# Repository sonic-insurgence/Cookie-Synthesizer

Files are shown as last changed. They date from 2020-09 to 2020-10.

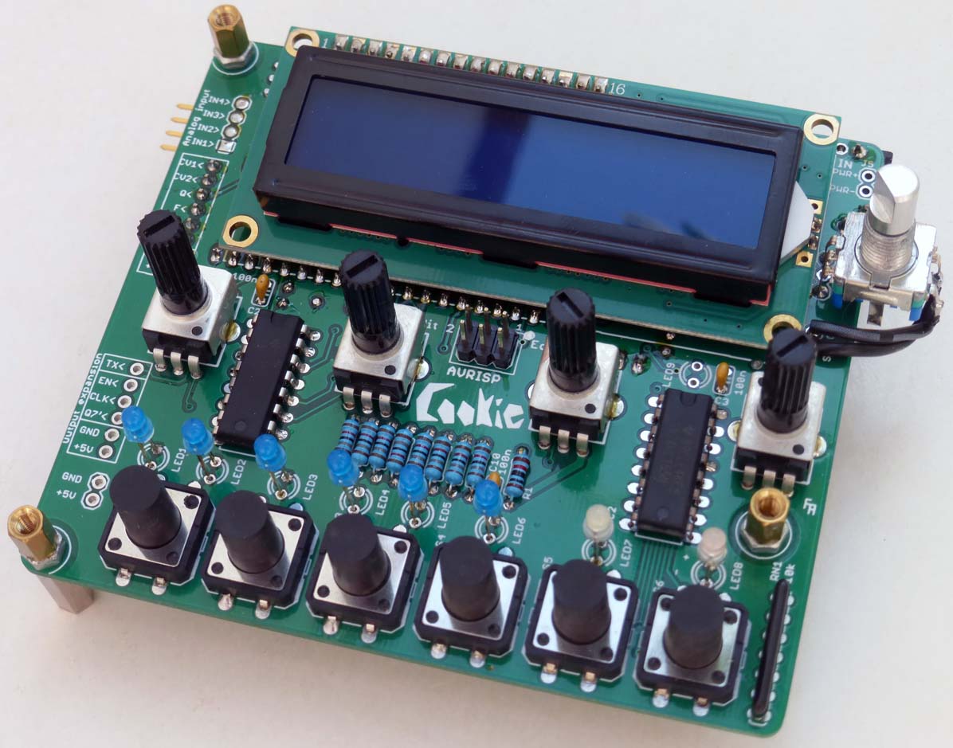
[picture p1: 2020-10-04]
documentation/images/controller board3.jpg

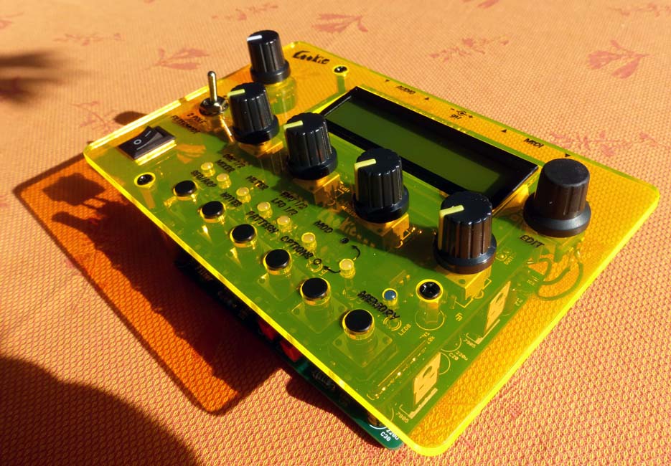
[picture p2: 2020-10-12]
documentation/images/Workshop Cookie Neon3.jpg

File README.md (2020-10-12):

# Cookie Synthesizer

The Cookie is a small but powerful DIY synthesizer project.
It is derived from the Shruthi-1 DIY hybrid synthesizer by Émilie Gillet 
from Mutable Instruments. 
Slight modifications have been carried out concerning the PCB form factor, the track layout 
and the arrangement of components. 
The circuit is basically the same as the "Shruthi-Digital-v08" with a "Shruthi-Analog-SMR4-mkII-v02" 
filter board.

### User Manual
Learn how to operate your Cookie Synth by having a look at the 
[user manual of the original Shruthi-1](https://mutable-instruments.net/archive/shruthi/manual/).

### Patch Editor
There are several editors out there that can be used to tweak the sounds on your Cookie Synth. 
E. g. check out the one from 
[Ixox (Win / OS X)](https://github.com/Ixox/Shruthi-And-Ambika-Editors/releases).
You may also find a patch manager software useful to organize your many sounds. 
If you are on Windows you might give  
[ShruthiFi1_0 (Win)](https://sites.google.com/site/thesonicfunk/programs) a try, although 
I had some issues with it.

### Firmware
The Cookie provides full software compatibility with Shruthi-1. You can flash the 
microcontroller with the original firmware from MI or with an alternative firmware like 
YAM by bjoeri. The software provided in this repository is a slight modification of the latter.
* https://github.com/pichenettes/shruthi-1
* https://github.com/bjoeri/shruthi-1

### Authors
* Author of the derived work, i. e. the Cookie synthesizer, is Sonic Insurgence.
* Author of the original work, i. e. the Shruthi-1 synthesizer, is Émilie Gillet.
* Author of the alternative firmware YAM is bjoeri.

### License
The Cookie schematics and PCB design files are licensed under a CreativeCommons CC-BY-SA license.
See: http://creativecommons.org/licenses/by-sa/3.0/

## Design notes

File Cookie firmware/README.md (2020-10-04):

# Cookie Synthesizer firmware

The Cookie Synth uses YAM0.05 alternative firmware for Shruthi-1 written by bjoeri.
I changed the splash screen to show "Cookie Synth" and removed "Mutable Instruments" because this is a registered trademark of Émilie Gillet.
To adapt for inverting opamps at the CV inputs the method "Ui::ScanPotentiometers()" in file "ui.cc" has been modified by adding the following line: 
```
    adc_.StartConversion(pots_multiplexer_address_);
    if (address >= 4) {
      value = 1023 - value;   // ### Cookie: invert external CV inputs CV1..4
      part.mutable_voice()->set_modulation_source(
          MOD_SRC_CV_1 + address - 4, value >> 2);
      address = 0xff;
    }
```

### User Manual
Have a look at the [user manual of the original Shruthi-1](https://mutable-instruments.net/archive/shruthi/manual/).

### YAM0.05 Differences / Improvements
Here's a short summary of changes compared to official Shruthi-1 firmware 1.02:

* PolyBlep implementations replace the original band-limited 'saw' and 'square' oscillators for higher fidelity and less memory footprint (Polyblep implementations inspired by, but less general than, Oliviers prototype for STM).
* 'square' is now a Polyblep oscillator with a more proper sounding PWM, i.e. more edginess, and no loudness drop for PWM modulation parameter above 0. (The original aliasing pwm is still available as 'dpwm'.)
* 'saw' is now a Polyblep oscillator (withuot any high pass pre-filtering and the modulation is different). The parameter for saw now add mix of a 2nd saw edge, resulting in a saw with sub oscillator (actually super oscillator) sound. 
* 'triangle' is no longer band-limited (to reduce memory footprint) and is folded (instead of clipped) upon modulation. This also means that the 'crush' oscillator is slightly different sounding.
* Added a 'csaw' Polyblep oscillator very similar to the CS-80 inspired saw oscillator for Braids. Without modulation it's a plain saw (identical to 'saw'). Modulation adds a 'notch' discontinuity before the ramp.
* Added a quad PWM oscillator ('qpwm') very similar to the quad saw ('pad'). The modulation parameter simultaneously affect both detuning of the four pwm oscillators, and the pulse width.
* Added an alternative FM oscillator ('fmfb') with feedback modulation. Just as for the regular FM oscillator, the modulation parameter defines the FM amount, but for modulation values above 64 increasing amount of feedback is added. At moderate levels the feedback adds 'grit'. At higher settings it adds digital distortion (deliberately left in).
* Added filter variations of CZ resonance saw and pulse waveforms ported from Ambika ('lpzsaw', 'pkzsaw', 'hpzsaw', 'lpzpulse', 'pkzpulse', 'hpzpulse'). In this new naming conventionm, the old 'zreso' is now named 'lpzsaw', and the old 'zpulse' is now named 'pkzpulse'.
* Added 'wavquence' oscillator (simply ported from the official Ambika firmware).
* Duo mode voice allocation reverted to 0.96 behaviour (because I subjectively think it's more enjoyable):
  - Press and hold C -> Osc1 plays C; then 
  - Press and hold E -> Osc2 plays C, Osc1 plays E 
  - (Sub is always assigned to lowest note)

Some tips on patch compatibility with official Shruthi-1 firmware:
Due to qualitative differences of the 'saw' and 'square' oscillators etc, levels may have to be adjusted somewhat to mimic original patches. If you really miss the original saw oscillator from the official firmware, this one is still available as 'oldsaw' (it's high-pass sampled and have a different character).

### How to make
- On a Mac install CrossPack-AVR with GCC Version 4.3.3: https://www.obdev.at/downloads/crosspack/CrossPack-AVR-20100115.dmg
- Connect an avrdude compatible programmer (e. g. AVRISP mkII) to the ISP connector on the Cookie and to a USB port on your computer.
Check the avrdude parameters in avrlib/makefile.mk.
- Use the terminal and go to the Cookie firmware directory.
- Make the bootloader first: make -f bootloader/makefile
- Then make the rest: make bake_all

### Authors
* Author of the original Shruthi-1 firmware is Émilie Gillet.
See https://github.com/pichenettes/shruthi-1
* Author of the alternative firmware YAM is bjoeri.
See https://github.com/bjoeri/shruthi-1

### License
The firmware is released under a GPL3.0 license. It includes a
reimplementation of the formant synthesis algorithm used in Peter Knight's
Cantarino speech synthesizer.

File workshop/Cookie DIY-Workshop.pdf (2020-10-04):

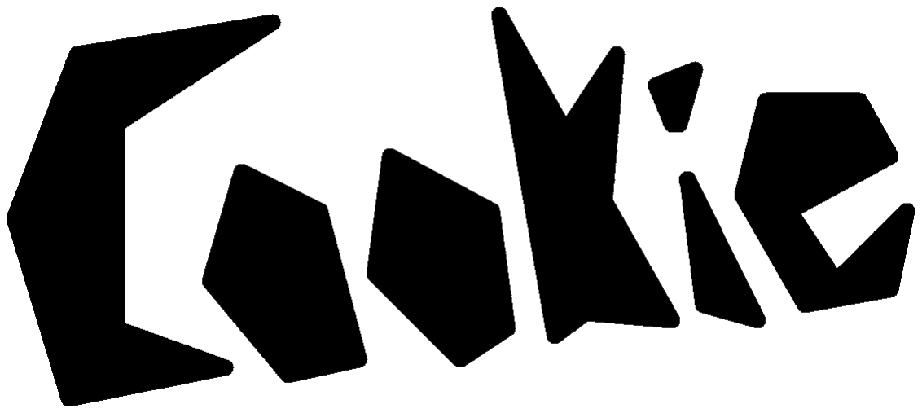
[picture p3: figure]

# Synthesizer DIY-Workshop

# Widerstand

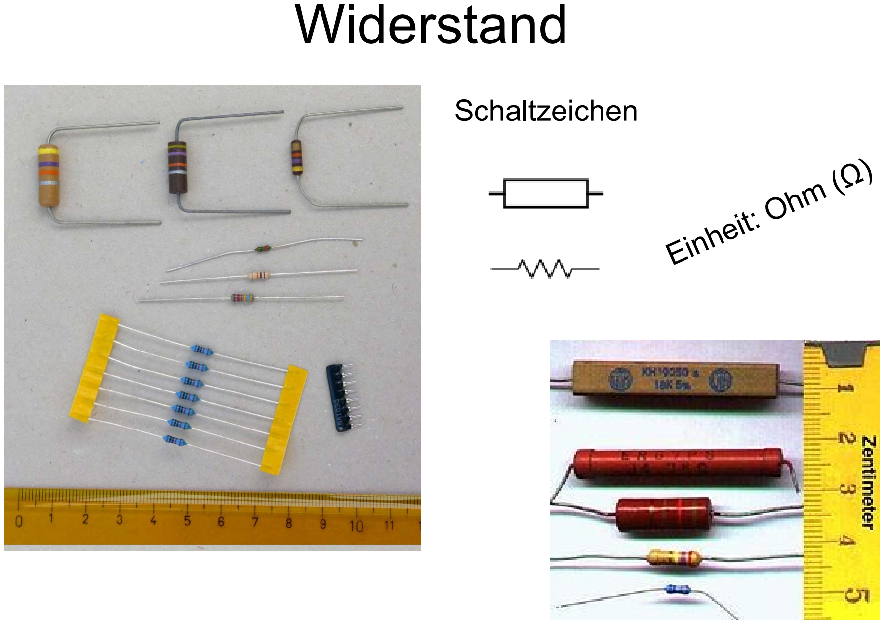
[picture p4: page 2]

Schaltzeichen
Einheit: Ohm (Ω)

# Kondensator

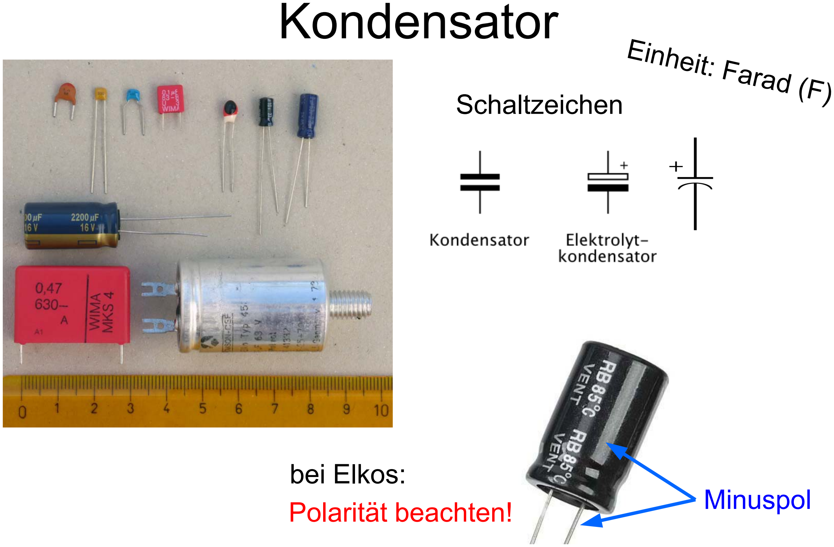
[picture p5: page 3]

Schaltzeichen

Einheit: Farad (F)

Polarität beachten!

bei Elkos:
Minuspol

# Diode

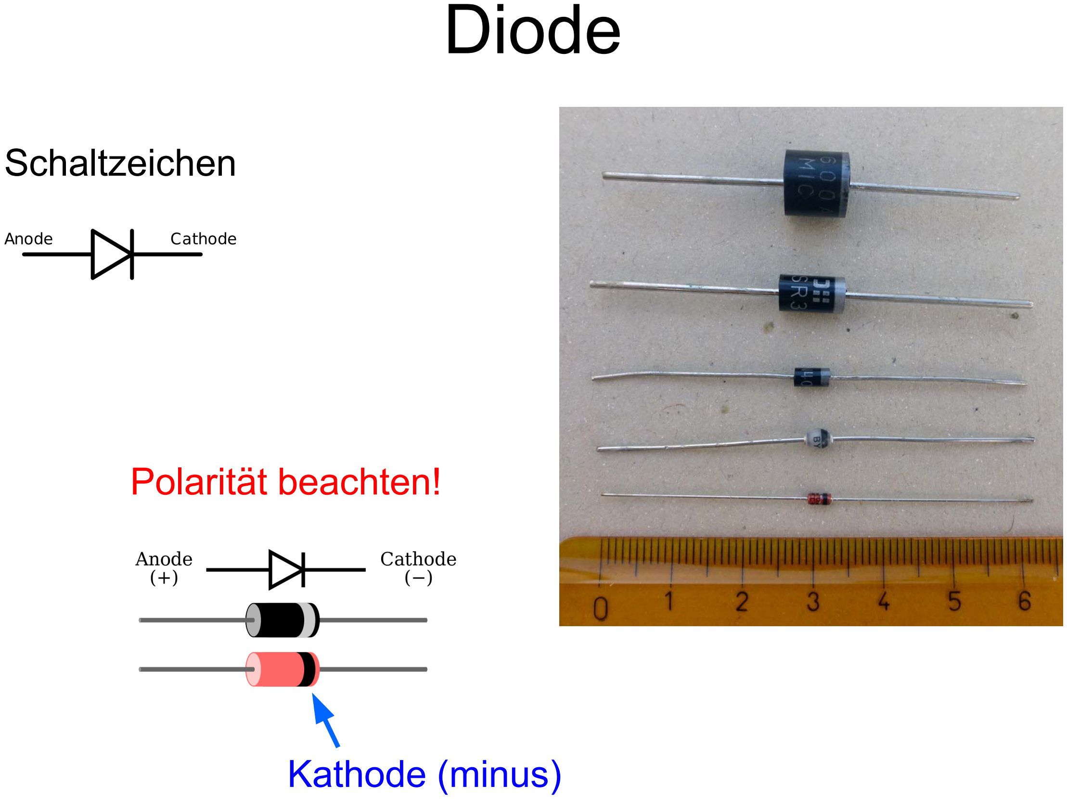
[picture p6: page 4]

Schaltzeichen

Polarität beachten!

Kathode (minus)

# Transistor

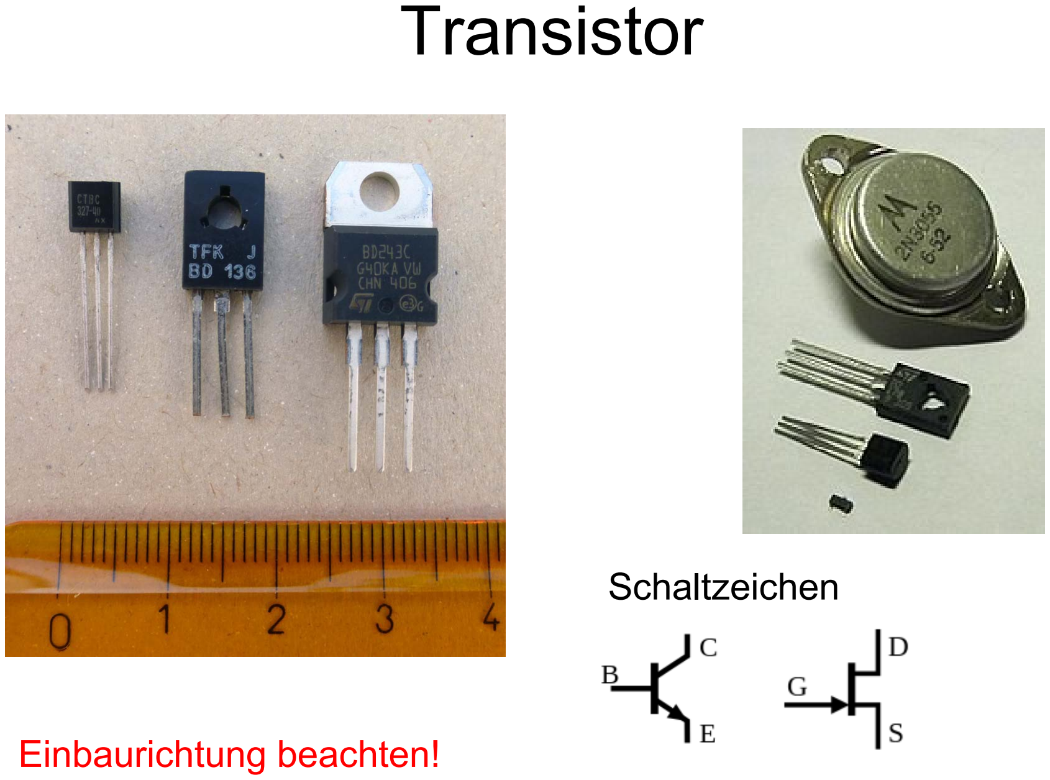
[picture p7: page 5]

Schaltzeichen

Einbaurichtung beachten!

# Integrierter Schaltkreis (IC)

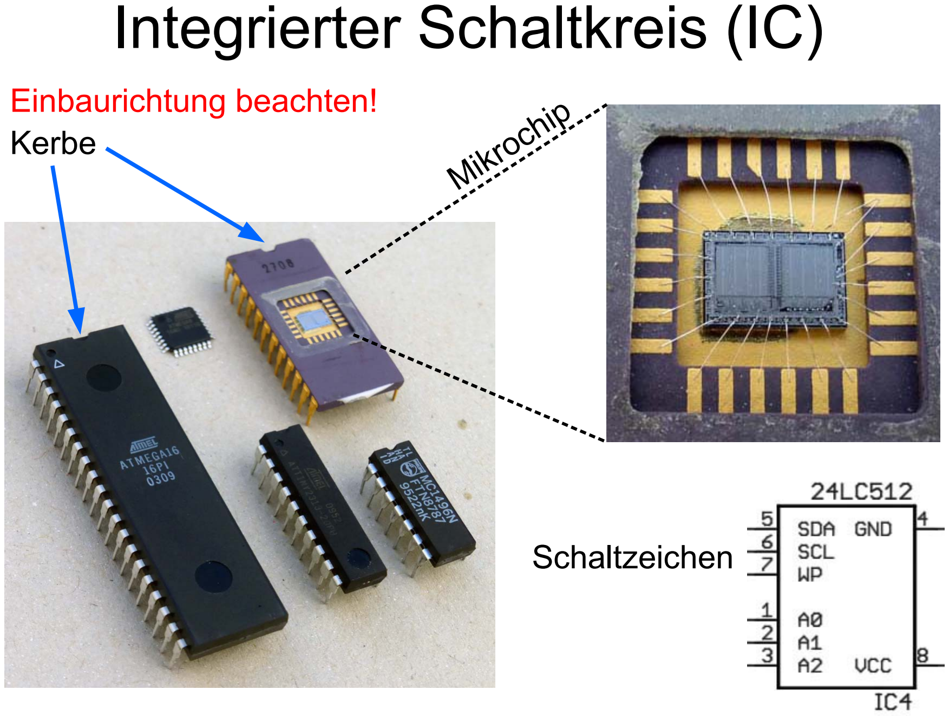
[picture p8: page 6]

Schaltzeichen

Mikrochip

Einbaurichtung beachten!
Kerbe

# Schaltplan lesen

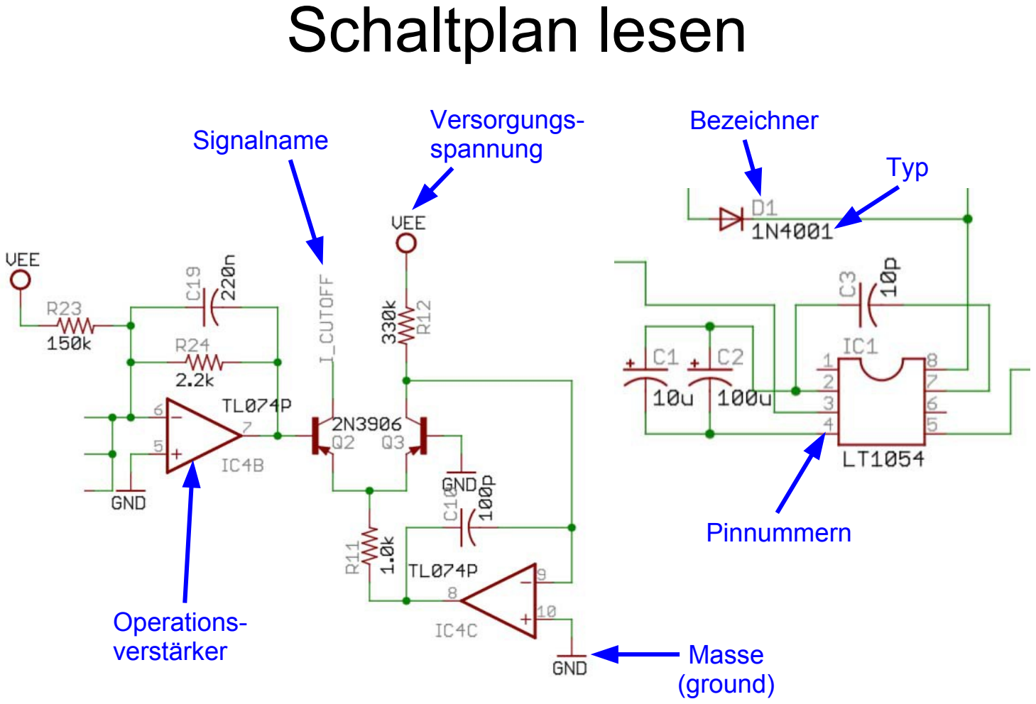
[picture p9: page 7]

Masse
(ground)

Bezeichner
Typ

Pinnummern

Signalname

Versorgungsspannung

Operationsverstärker

# BOM (bill of material)

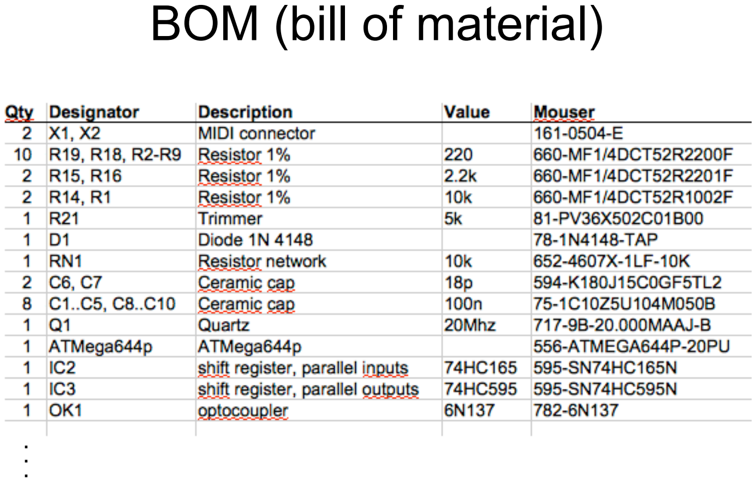
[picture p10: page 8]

# Einheiten

1 Ω
1 kΩ = 1.000 Ω
1 MΩ = 1.000.000 Ω

1 F
1 µF (mikro) = | 0.000001 F
1 nF (nano) = | 0.000000001 F
1 pF (pico) = 0.000000000001 F

Kurzschreibweise
4.7 kΩ → 4k7
2.2 MΩ → 2M2

Kurzschreibweise
6.8 µF → 6µ8 oder 6u8
100 nF → 100n
8.2 pF → 8p2

Bei den Kurzschreibweisen ergibt sich die Einheit
aus dem Schaltzeichen (Widerstand, Kondensator etc.).

# Kondensatorwerte

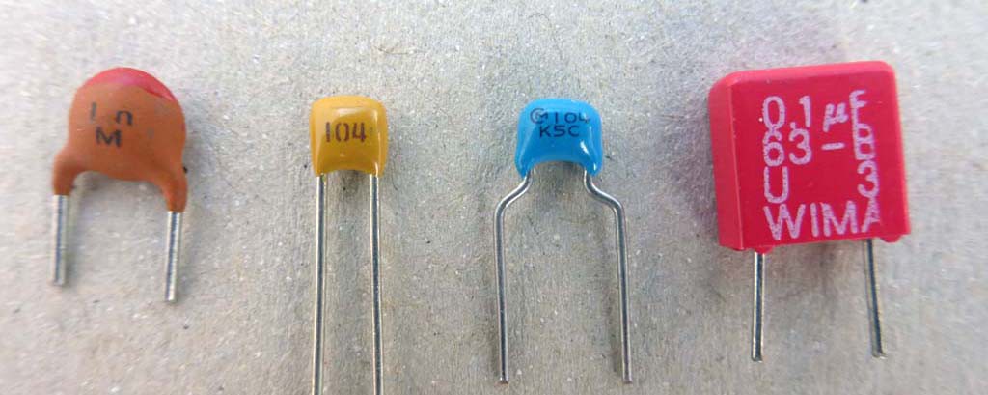
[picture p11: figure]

Die Art der Wertangabe von Kondensatoren variiert. 1 n → 1 nF
104 → 1 0 0000 pF = 100 nF
0.1 µF → So wünscht man sich das!

# Farbcode von Widerständen

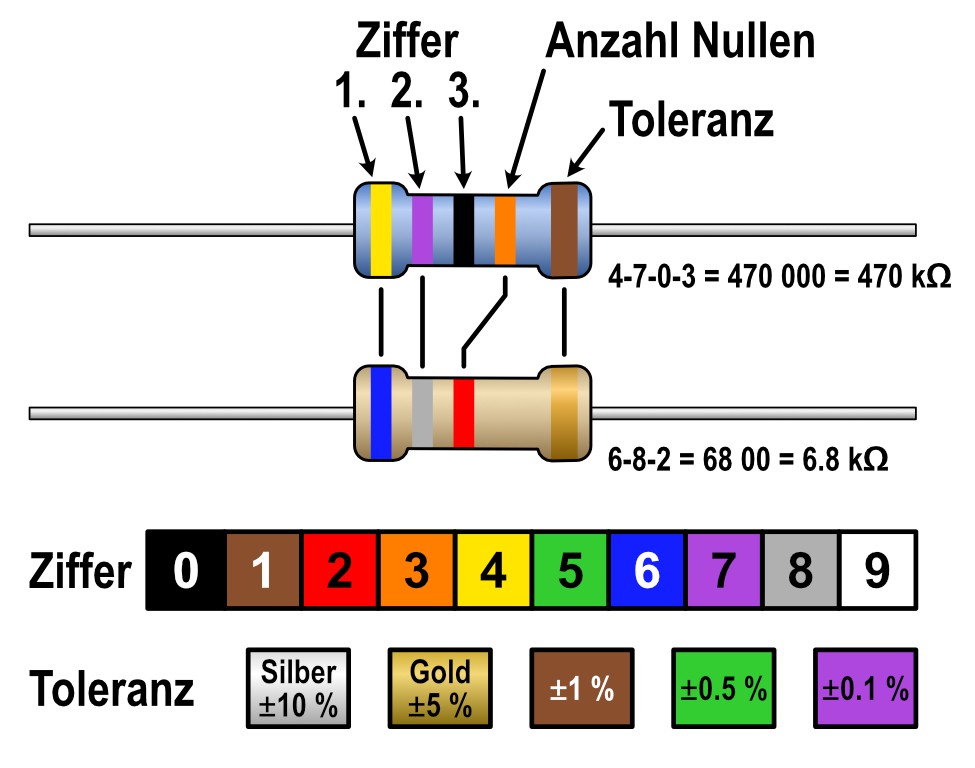
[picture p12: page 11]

# Übung Widerstandswerte

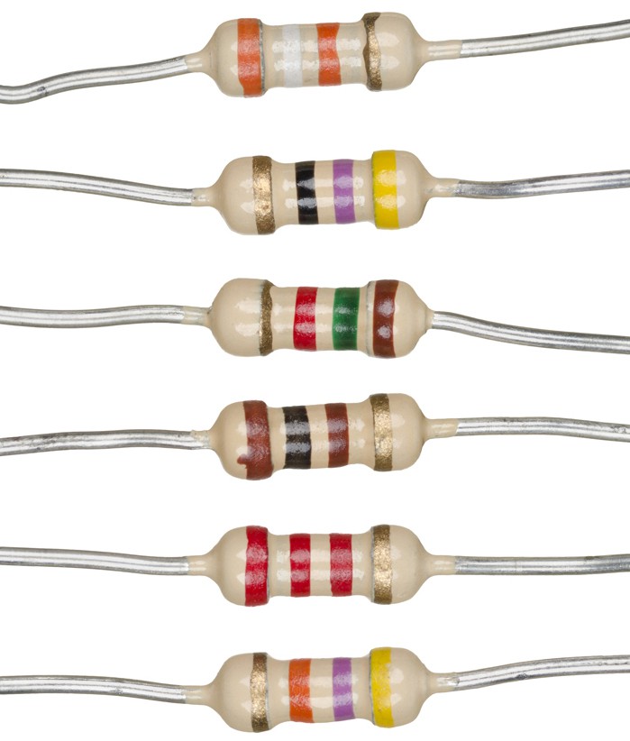
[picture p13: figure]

3-9-3 → 3 9 000 | = 39k
4-7-0 → 4 7 – | = 47
1-5-2 → 1 5 00 | = 1k5
1-0-1 → 1 0 0 | = 100
2-2-2 → 2 2 00 | = 2k2
4-7-3 → 4 7 000 | = 47 kΩ

alle: ±5 % Toleranz

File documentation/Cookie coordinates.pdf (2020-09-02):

Object | | | | | | Shruthi-1
| [mm] | [mm] | [mil] | [mil] | [mm]
| 99,7 | 87,6 | 3925 | 3450 | n. a. | no
| 3,2 | 3,2 | 125 | 125 | 3,0 | yes
| 3,2 | 84,5 | 125 | 3325 | 3,0 | yes
| 92,7 | 26,0 | 3650 | 1025 | 3,0 | no
| 12,1 | 39,4 | 475 | 1550 | 7,0 | yes
| 38,7 | 39,4 | 1525 | 1550 | 7,0 | yes
| 65,4 | 39,4 | 2575 | 1550 | 7,0 | yes
| 92,1 | 39,4 | 3625 | 1550 | 7,0 | yes
| 17,1 | 8,9 | 675 | 350 | 7,0 | yes
| 31,1 | 8,9 | 1225 | 350 | 7,0 | yes
| 45,1 | 8,9 | 1775 | 350 | 7,0 | yes
| 59,1 | 8,9 | 2325 | 350 | 7,0 | yes
| 73,0 | 8,9 | 2875 | 350 | 7,0 | yes
| 87,0 | 8,9 | 3425 | 350 | 7,0 | yes
LED1 | 12,7 | 19,1 | 500 | 750 | 3,0 | yes
LED2 | 21,0 | 19,1 | 825 | 750 | 3,0 | yes
LED3 | 31,1 | 19,1 | 1225 | 750 | 3,0 | yes
LED4 | 41,3 | 19,1 | 1625 | 750 | 3,0 | yes
LED5 | 49,5 | 19,1 | 1950 | 750 | 3,0 | yes
LED6 | 59,1 | 19,1 | 2325 | 750 | 3,0 | yes
LED7 | 73,0 | 19,1 | 2875 | 750 | 3,0 | yes
LED8 | 87,0 | 19,1 | 3425 | 750 | 3,0 | yes
LED9 | 80,0 | 46,4 | 3150 | 1825 | 3,0 | no
Midi In (X1) | 90,8 | 88,3 | 3575 | 3475 | 15,0 | yes
Midi Out (X2) | 70,5 | 88,3 | 2775 | 3475 | 15,0 | yes
| 10,2 | 87,6 | 400 | 3450 | 4,0 | yes
| 101,6 | 64,8 | 4000 | 2550 | 7,0 | yes
LCD pin1 | 20,7 | 83,4 | 815 | 3285 | n. a. | yes
center of LCD-screen | 52,7 | 67,4 | 71,5 x 24,5 | yes
CV1 | 6,4 | 64,8 | 250 | 2550 | yes
CV2 | 6,4 | 62,2 | 250 | 2450 | yes
Q | 6,4 | 59,7 | 250 | 2350 | yes
F | 6,4 | 57,2 | 250 | 2250 | yes
VCA | 6,4 | 54,6 | 250 | 2150 | yes
OSC | 6,4 | 52,1 | 250 | 2050 | yes
GND | 6,4 | 49,5 | 250 | 1950 | yes
+5V | 6,4 | 47,0 | 250 | 1850 | yes
TX | 6,4 | 31,1 | 250 | 1225 | yes
EN | 6,4 | 28,6 | 250 | 1125 | yes
CLK | 6,4 | 26,0 | 250 | 1025 | yes
Q7 | 6,4 | 23,5 | 250 | 925 | yes
GND | 6,4 | 21,0 | 250 | 825 | yes
+5V | 6,4 | 18,4 | 250 | 725 | yes
Shruthi-1
IN4 | 7,0 | 76,2 | 275 | 3000 | no | 250 | 2950
IN3 | 7,0 | 73,7 | 275 | 2900 | no | 250 | 2850
IN2 | 7,0 | 71,1 | 275 | 2800 | no | 250 | 2750
IN1 | 7,0 | 68,6 | 275 | 2700 | no | 250 | 2650

## Cookie Synth Dimensions

Origin: lower left corner

x-coord | y-coord | x-coord | y-coord | drill diameter
compatible
board size
spacer 1
spacer 2
spacer 3
potentiometer 1
potentiometer 2
potentiometer 3
potentiometer 4
push-button 1
push-button 2
push-button 3
push-button 4
push-button 5
push-button 6

LCD contrast (R21)
rotary encoder

pins of filter board connector

pins of spi connector

analog input pins | positions

Object
| [mm] | [mm] | [mil] | [mil] | [mm]
| 99,7 | 87,6 | 3925 | 3450 | n. a.
| 3,2 | 3,2 | 125 | 125 | 3,0
| 3,2 | 84,5 | 125 | 3325 | 3,0
| 92,7 | 26,0 | 3650 | 1025 | 3,0
audio in (J7) | 22,2 | 88,3 | 875 | 3475 | 11,0
audio out 1 (J8) | 40,6 | 88,3 | 1600 | 3475 | 11,0
audio out 2 (J9) | -2,4 | 20,1 | -95 | 790 | 11,0
| 54,6 | 88,3 | 2150 | 3475 | 6,0
| 0,0 | 35,6 | 0 | 1400 | 4,0

## Cookie Filter Dimensions

Origin: lower left corner

x-coord | y-coord | x-coord | y-coord | drill diameter

board size
spacer 1
spacer 2
spacer 3

supply (J1)
V/Oct (R33)

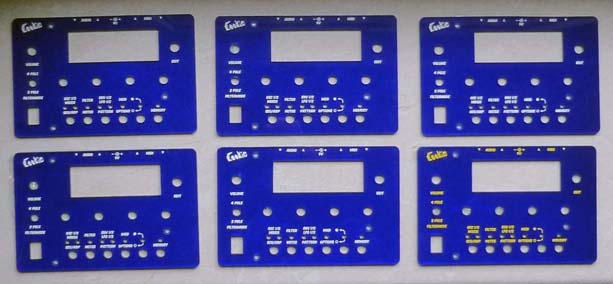
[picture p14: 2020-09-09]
documentation/images/Workshop Cookie Frontpanels.jpg

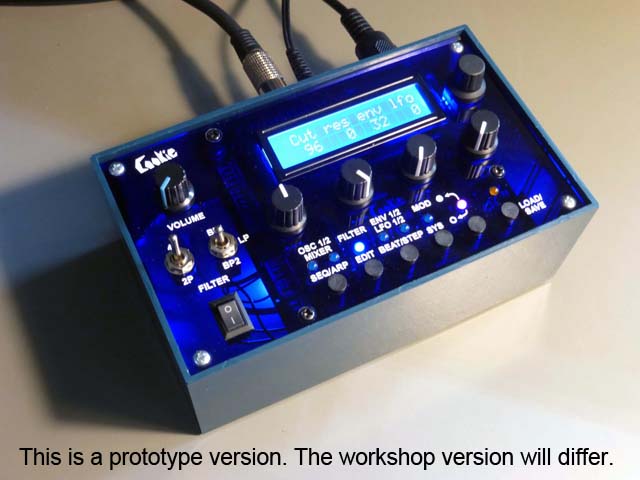
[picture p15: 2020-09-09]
documentation/images/Cookie Prototype.jpg

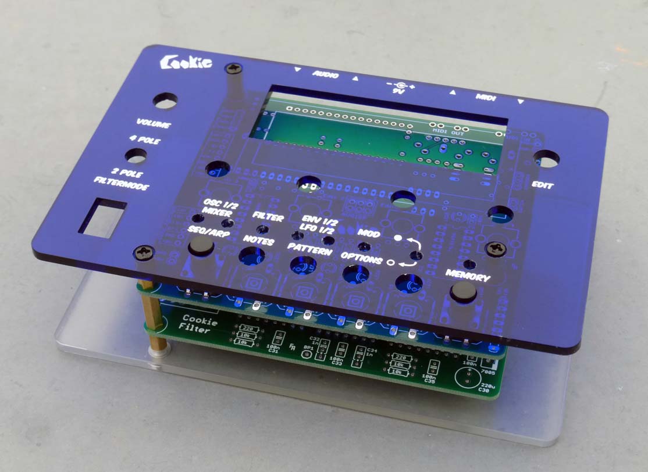
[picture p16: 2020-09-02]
documentation/images/Workshop Cookie Mockup2.jpg

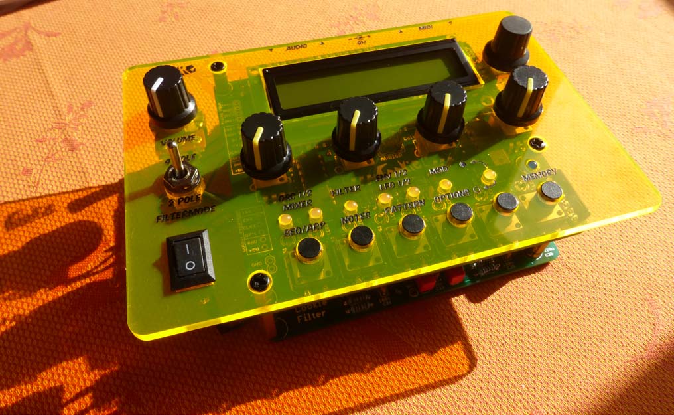
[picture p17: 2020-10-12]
documentation/images/Workshop Cookie Neon2.jpg

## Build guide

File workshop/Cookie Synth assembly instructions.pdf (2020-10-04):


# Bauanleitung

# Lötstellen

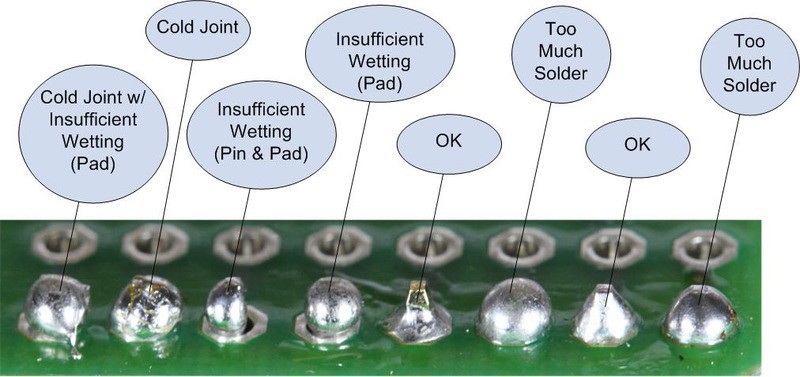
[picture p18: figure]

# Digital Controller Board

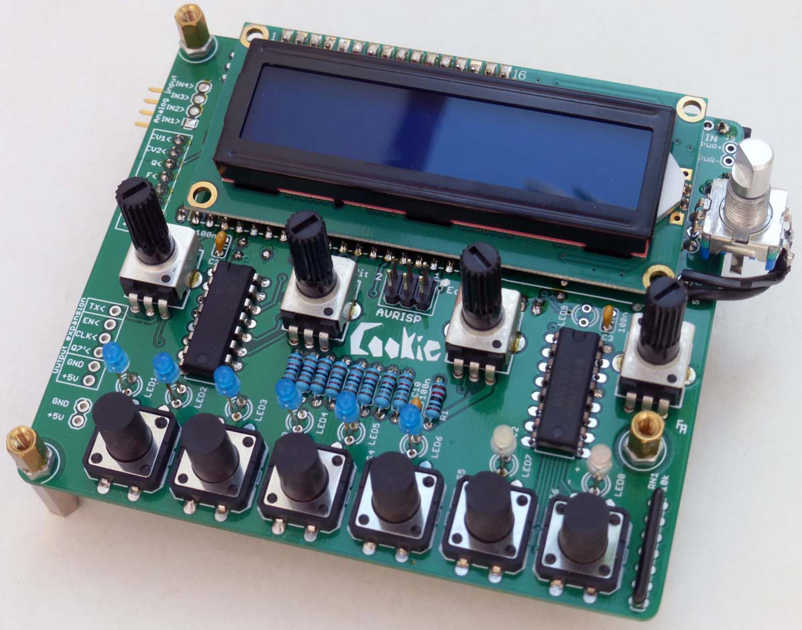
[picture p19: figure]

Cookie Synth – Controller Board | 4
R15, R16
→ 2.2 kΩ

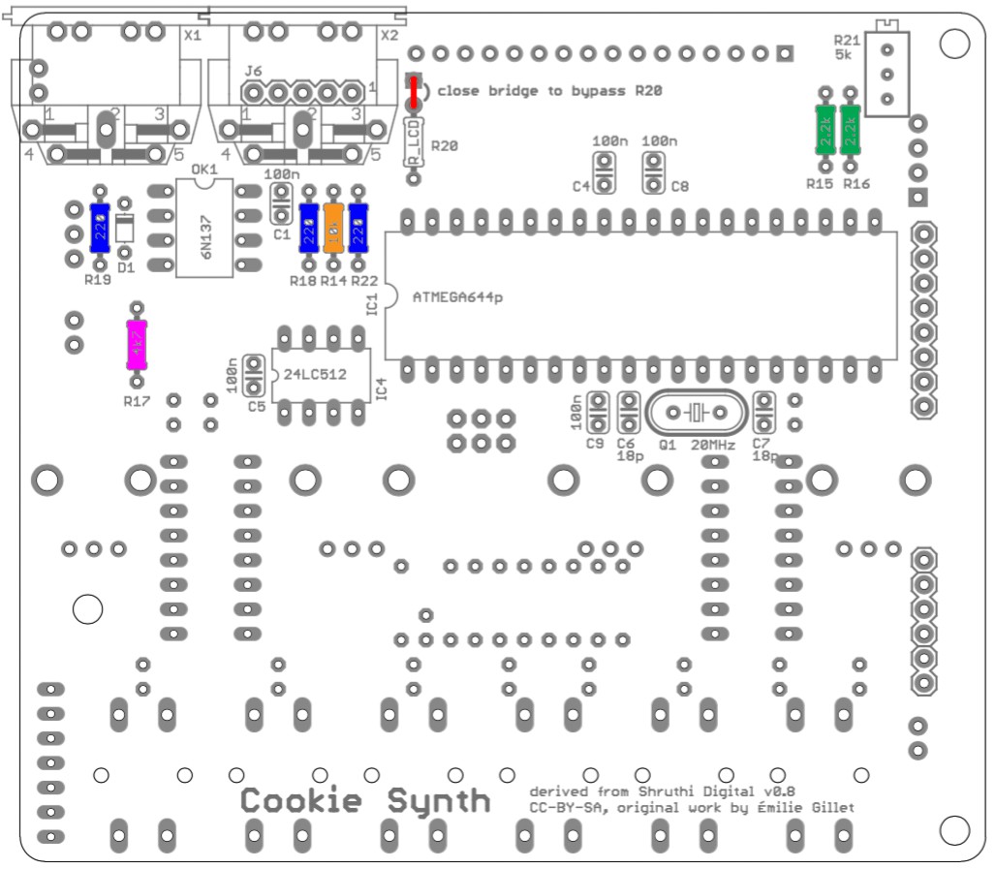
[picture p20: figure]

R18, R19, R22
→ 220 Ω

R17
→ 4.7 kΩ

R14
→ 10 kΩ

Drahtbrücke

Cookie Synth – Controller Board | 5
D1
→ 1N4148
Polarität
beachten!
| C1, C4, C5, C8,
C9
→ 100 nF
(Aufdruck 104)

Q1
→ 20 MHz

C6, C7
→ 18 pF
(Aufdruck 18)

Cookie Synth – Controller Board | 6
IC1, IC4, OK1
→ Sockel

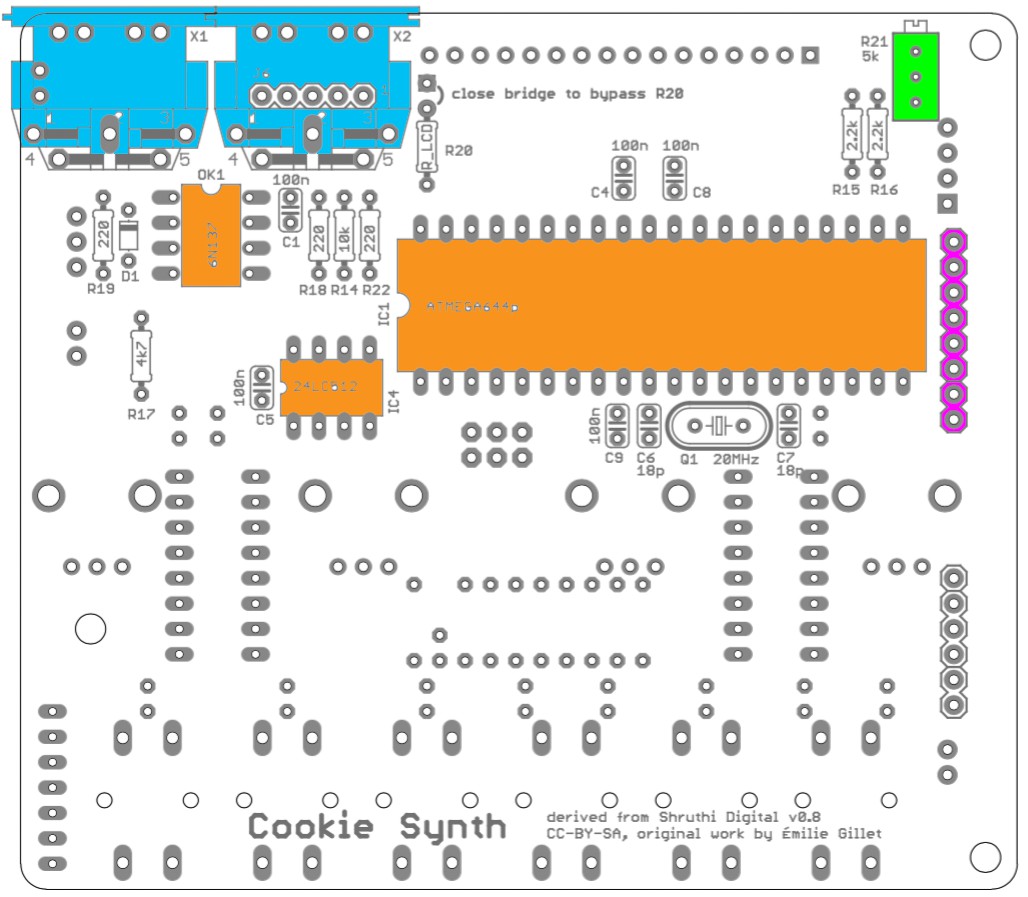
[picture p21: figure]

Auf richtige
Orientierung
(Kerbe im
Sockel) achten!

Stiftleiste
→ 8 Pins
(senkrecht zur
Platine)

R21
→ Trimmer 5 kΩ

X1, X2
→ DIN-Buchsen

Cookie Synth – Controller Board | 7

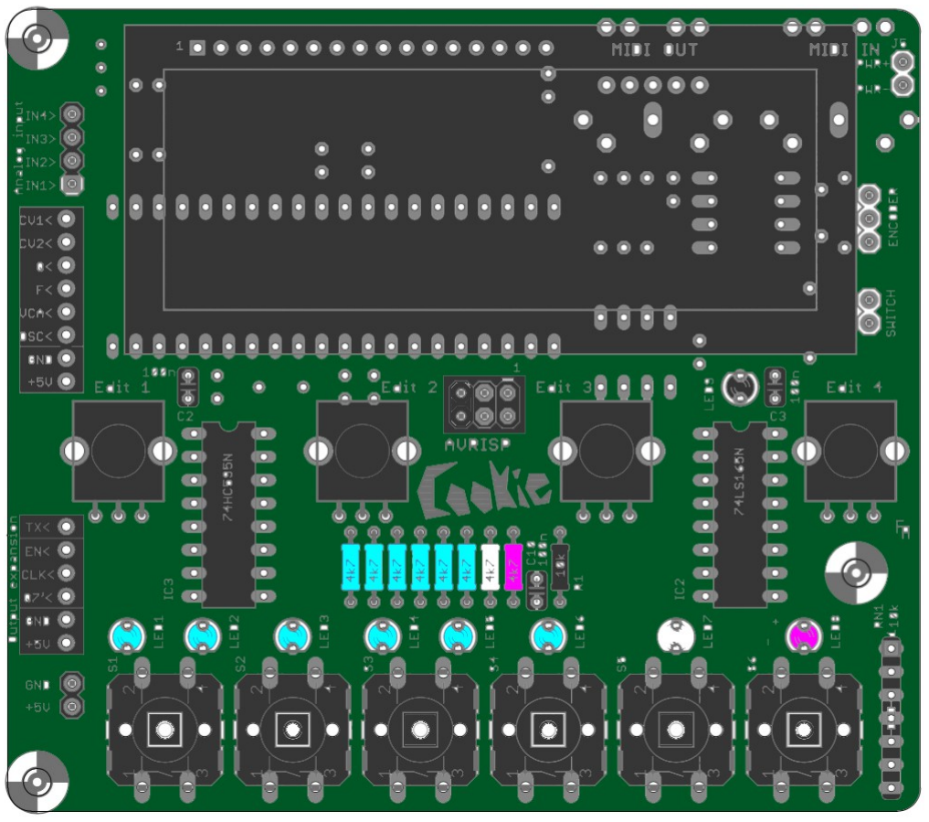
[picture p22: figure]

LED-Vorwiderstände

grün → 1 kΩ
gelb → 4.7 kΩ
rot → 10 kΩ
orange → 6.8 kΩ
blau → 18 kΩ
weiß → 15 kΩ
pink → 18 kΩ

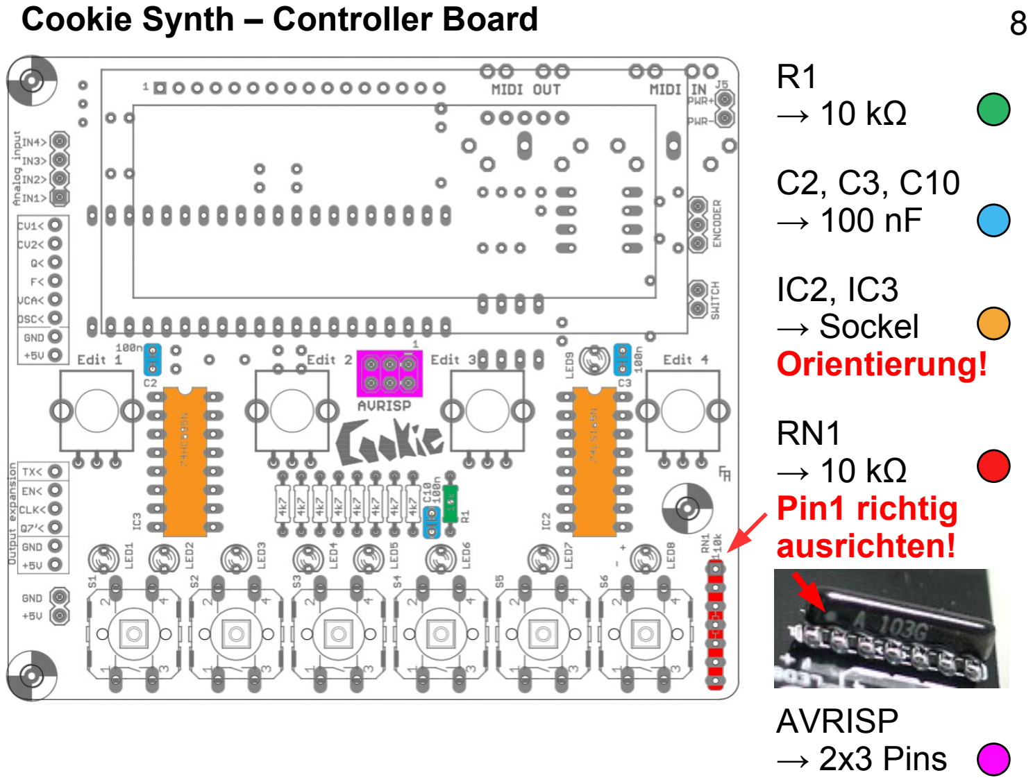
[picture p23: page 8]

Cookie Synth – Controller Board | 8
R1
→ 10 kΩ

C2, C3, C10
→ 100 nF

IC2, IC3
→ Sockel
Orientierung!

RN1
→ 10 kΩ
Pin1 richtig
ausrichten!

AVRISP
→ 2x3 Pins

Cookie Synth – Controller Board | 9
S1..6
→ Taster

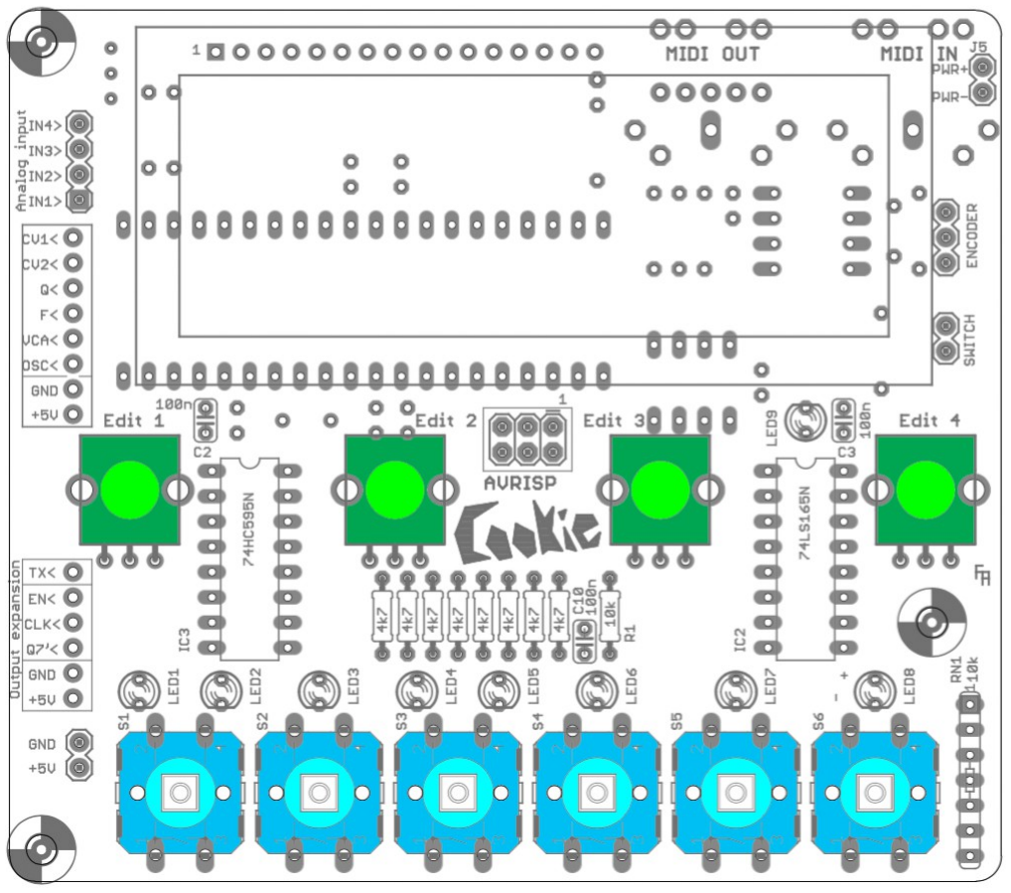
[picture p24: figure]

Edit1..4
→ Poti 10 kΩ

Hinweis:
Taster und
Potis müssen
flach aufliegen.

Cookie Synth – Controller Board | 10
| Bauteile zunächst nur
einsetzen:

ENCODER

LED1..8
| Polarität beachten!
langes Beinchen =
Anode (nach oben)
| abgeflachte Seite = Kathode (nach unten)

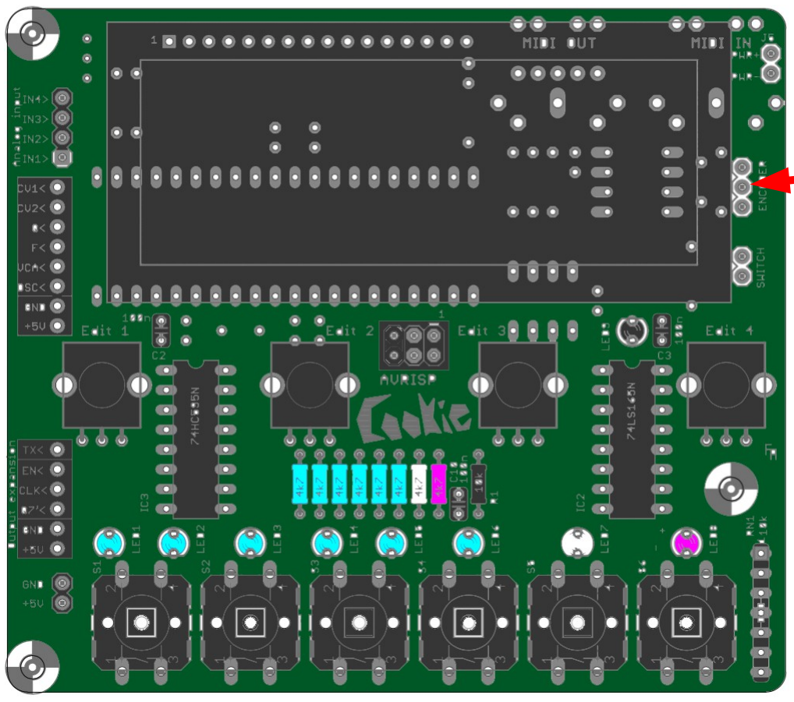
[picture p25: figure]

Hinweis: Vor dem Verlöten die Frontplatte provisorisch montieren und den Encoder lose anschrauben. Die LEDs in die Bohrungen führen, damit Position und Abstand stimmen. Dann löten.

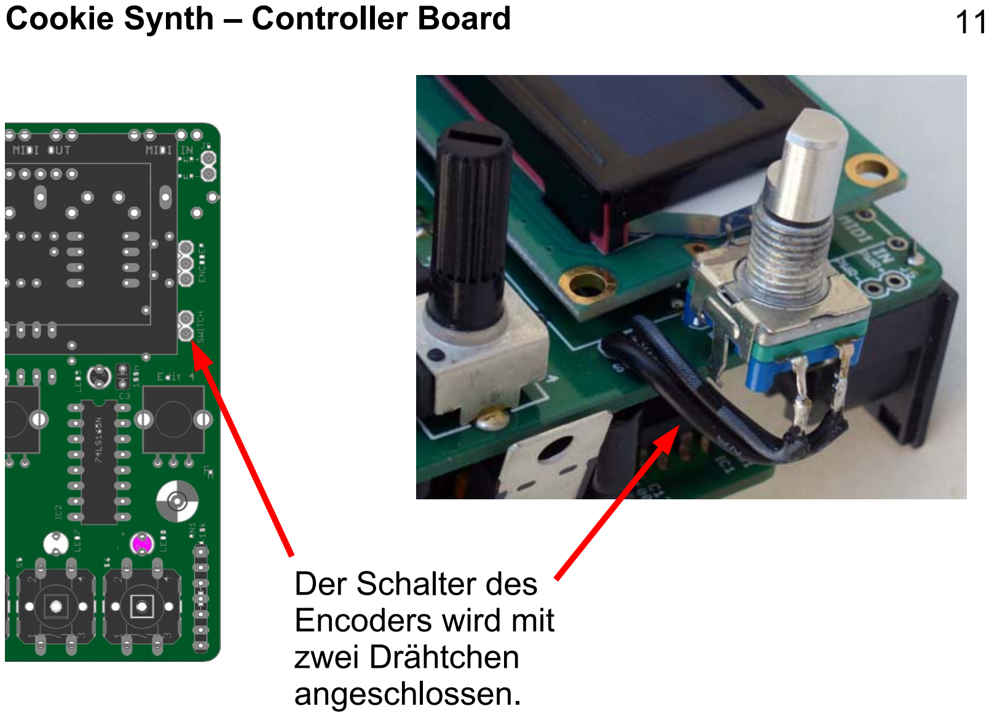
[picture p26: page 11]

Cookie Synth – Controller Board | 11

Der Schalter des
Encoders wird mit
zwei Drähtchen
angeschlossen.

Cookie Synth – Controller Board | 12
ICs einsetzen.
| Kerbe am IC muss mit der Kerbe am Sockel

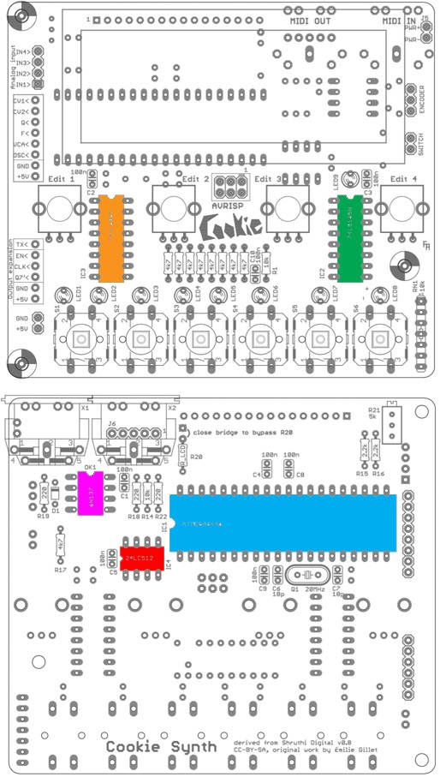
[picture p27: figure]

übereinstimmen.

IC1
→ ATmega644PA

IC2
→ 74HC165

IC3
→ 74HC595

IC4
→ 24LC512

OK
→ 6N137

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
Cookie Synth – Controller Board | 13

Funktionstest

1) An die Stiftleiste eine Spannung von 5 Volt anlegen
(GND = Minus, +5V = + 5 Volt).

→ Alle LEDs leuchten kurz auf. Danach leuchten LED3 und LED7 dauernd.

2) Tasten drücken und Encoder drehen.

→ Lightshow bewundern

Cookie Synth – Controller Board | 14 Stiftleiste (16-polig) mit den kurzen Stiftenden nur an den

beiden äußeren Pins senkrecht in die Platine löten.

| LCD einsetzen und in Front-
plattenöffnung einpassen.

Die Stiftleiste ist etwas abgewinkelt. Hierdurch kann
das LCD leicht geneigt
werden.

LCD von unten mit einem
| Lötpunkt fixieren, Frontplatte
entfernen und LCD fertig
einlöten.

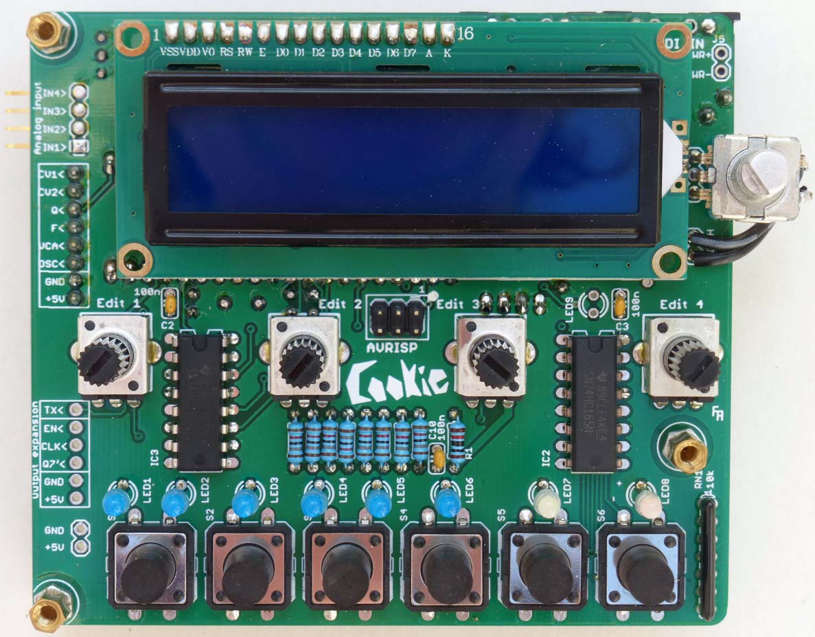
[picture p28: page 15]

Cookie Synth – Controller Board | 15

# Geschafft!

# Das erste Board

ist fertig.

# Analog Filter Board

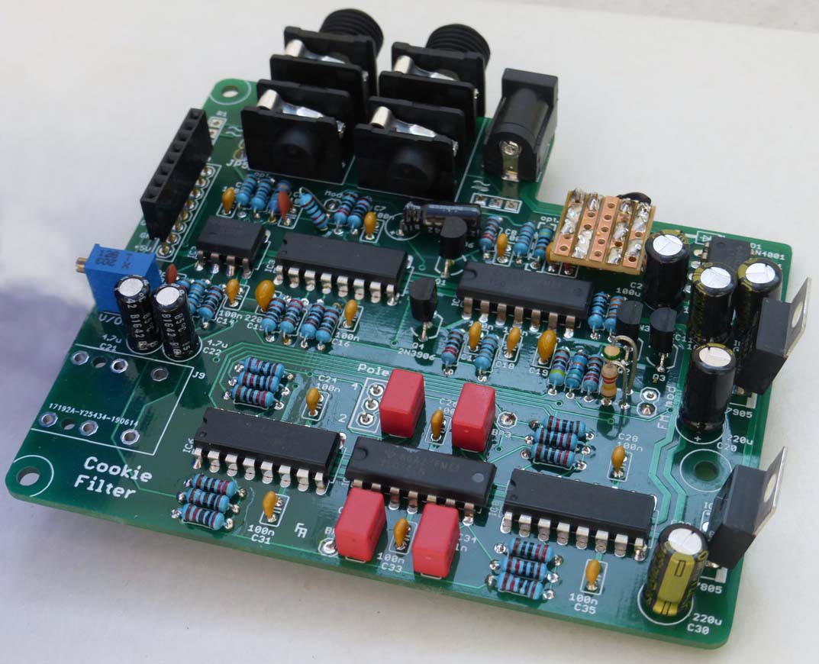
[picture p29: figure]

Cookie Synth – Filter Board | 18
D1
→ 1N4001
Polarität
beachten!

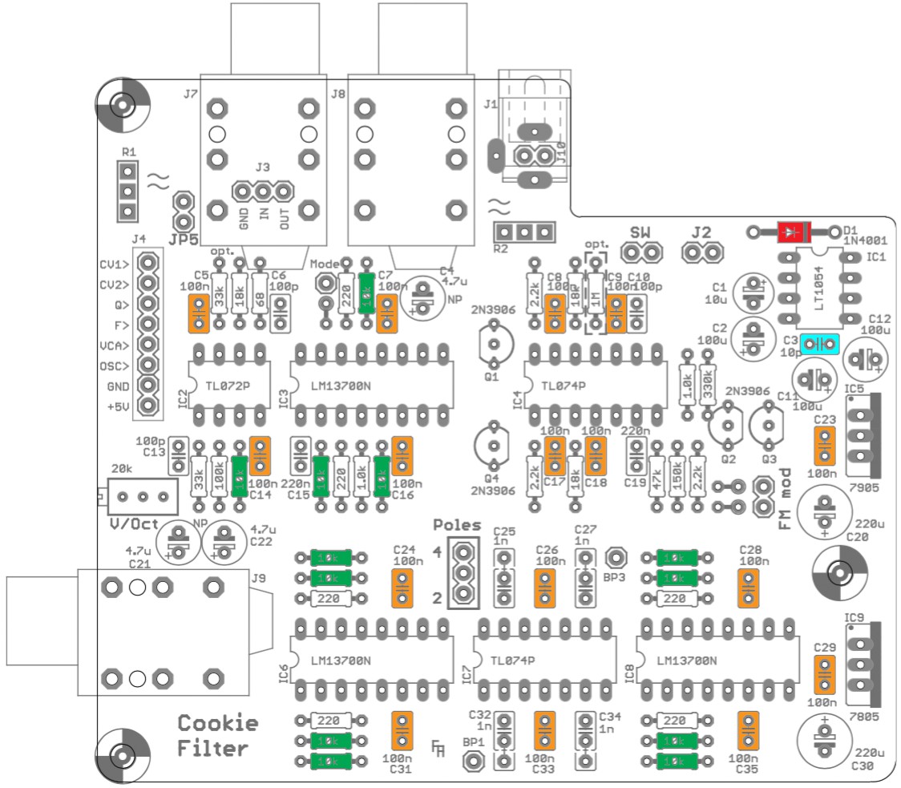
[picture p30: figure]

→ 12 x 10 kΩ

C3
→ 10 pF
(Aufdruck 10)
| C5, C7, C8, C9, C14, C16, C17, C18, C23, C24, C26, C28, C29, C31, C33, C35 → 16 x 100 nF (Aufdruck 104)

Cookie Synth – Filter Board | 19
1 x 68 Ω

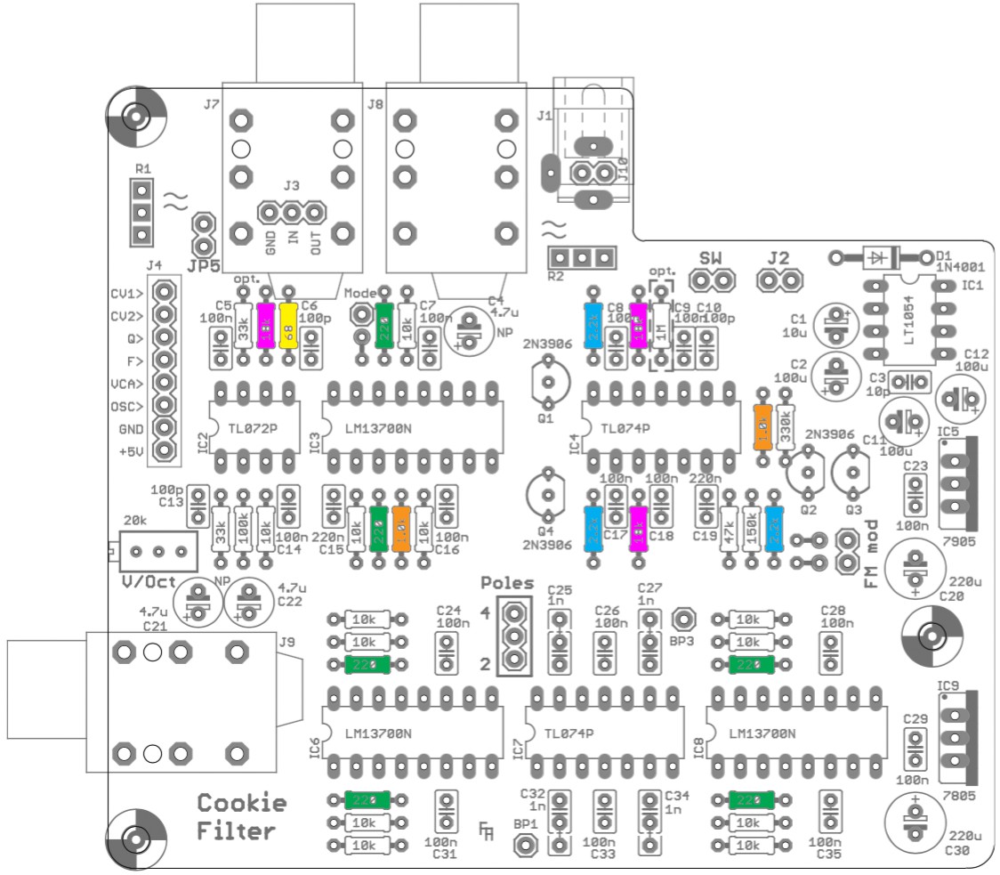
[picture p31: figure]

6 x 220 Ω

2 x 1 kΩ

3 x 2.2 kΩ

3 x 18 kΩ

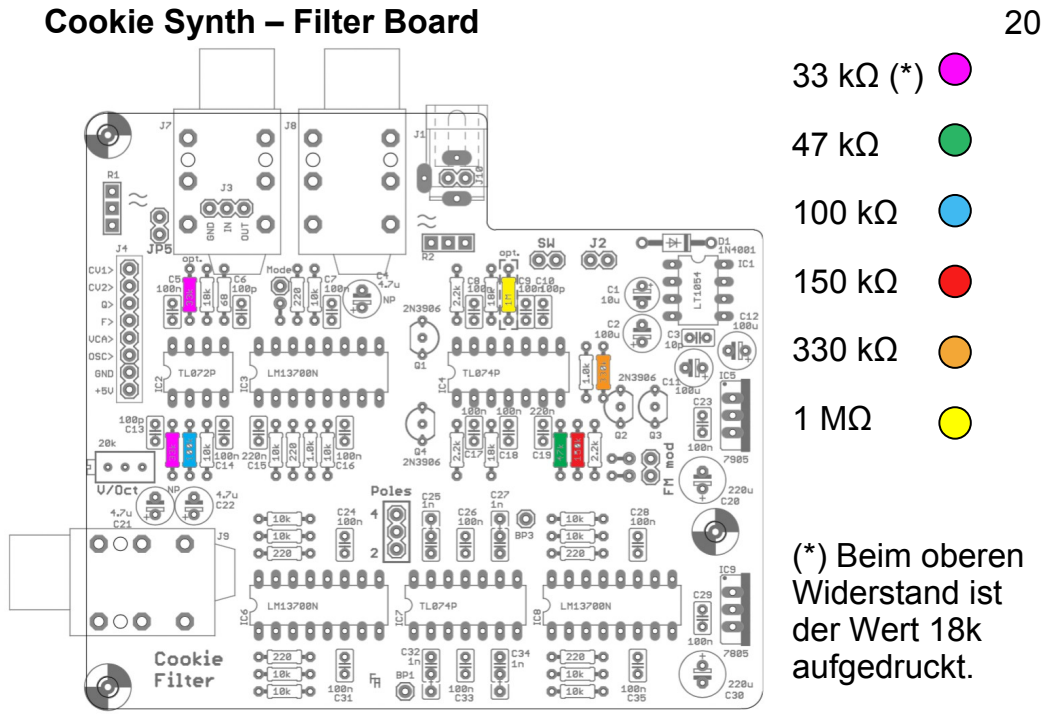
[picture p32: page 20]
Cookie Synth – Filter Board; (*) Beim oberen Widerstand ist der Wert 18k aufgedruckt.

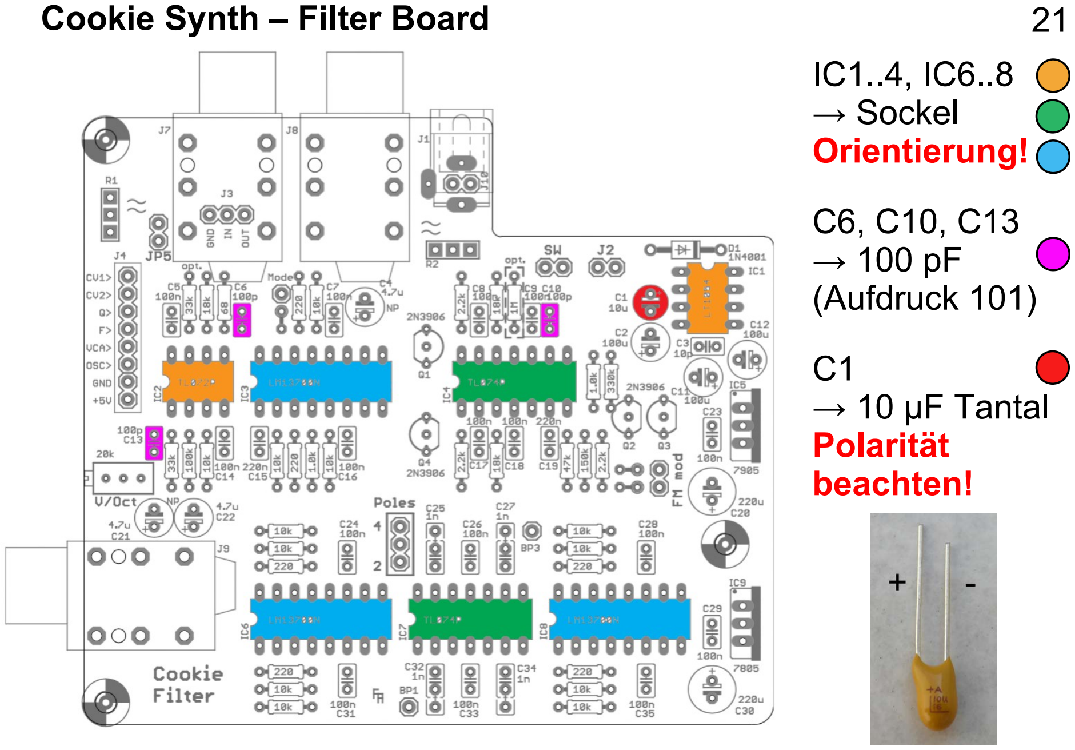
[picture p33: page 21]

Cookie Synth – Filter Board | 21
IC1..4, IC6..8
→ Sockel
Orientierung!

C6, C10, C13
→ 100 pF
| (Aufdruck 101)

C1
| → 10 µF Tantal
Polarität
beachten!

Cookie Synth – Filter Board | 22
C15, C19
→ 220 nF
(Aufdruck 224)

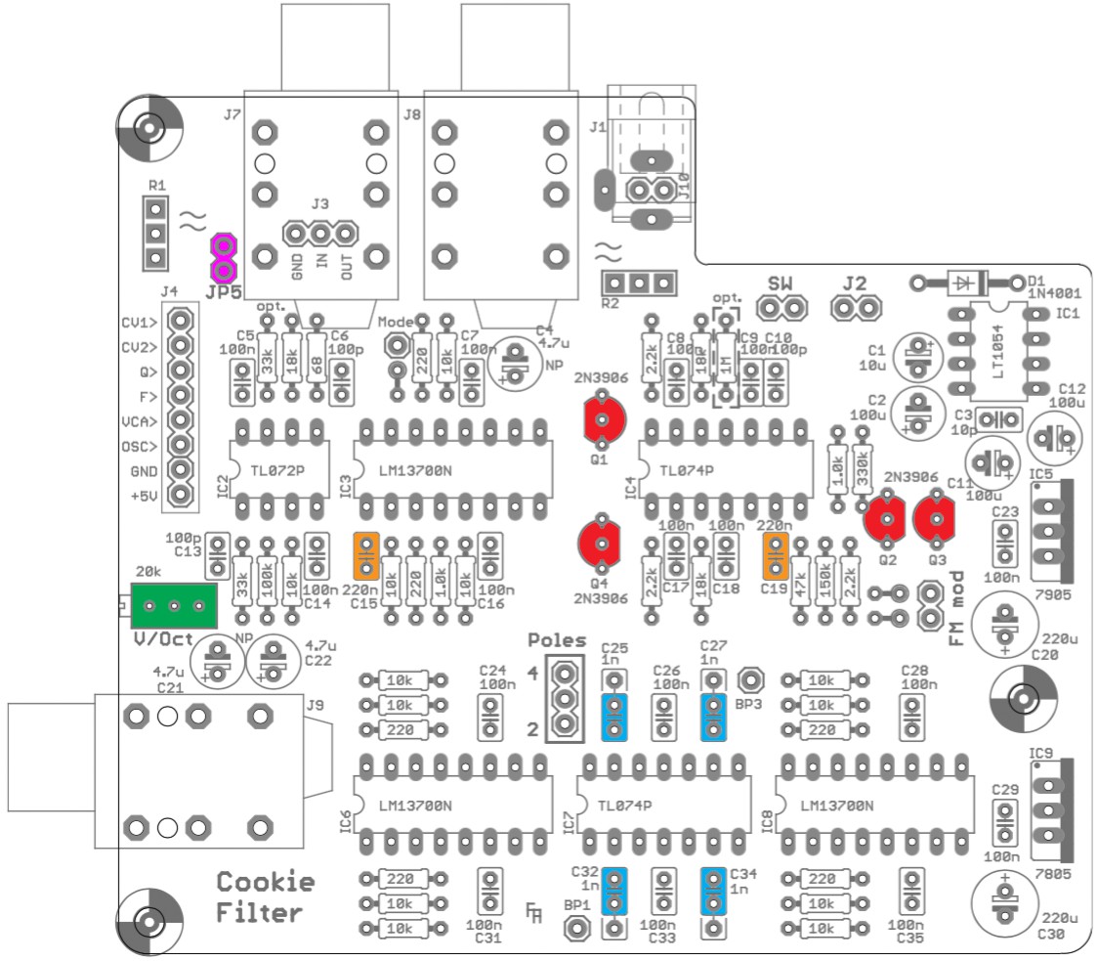
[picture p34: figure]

C25, C27, C32,
C34
→ 1 nF
| (rotes Klötzchen)

Q1..4
→ 2N3906
Orientierung!

JP5
→ Pfostenleiste

R33
| → Trimmer 20 kΩ

Cookie Synth – Filter Board | 23
C4, C21, C22
→ 4.7 µF
| (bipolare Elkos,
Polarität egal)
C4 liegend!

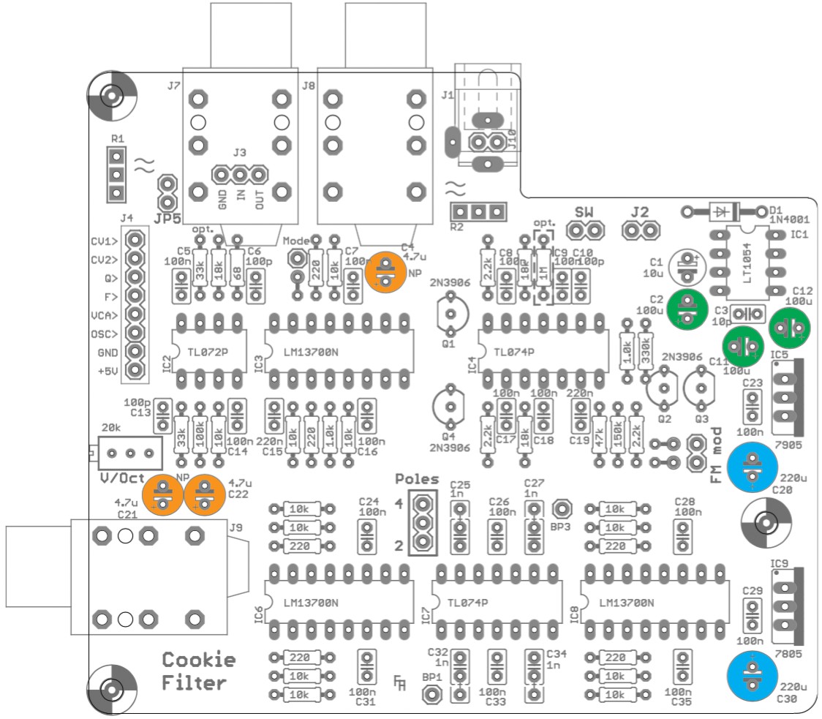
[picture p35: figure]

C2, C11, C12
→ 100 µF
Polarität
beachten!

C20, C30
→ 220 µF
Polarität
beachten!

100 µF und
220µF sehen
gleich aus!

Cookie Synth – Filter Board | 24
J1
→ DC-Buchse

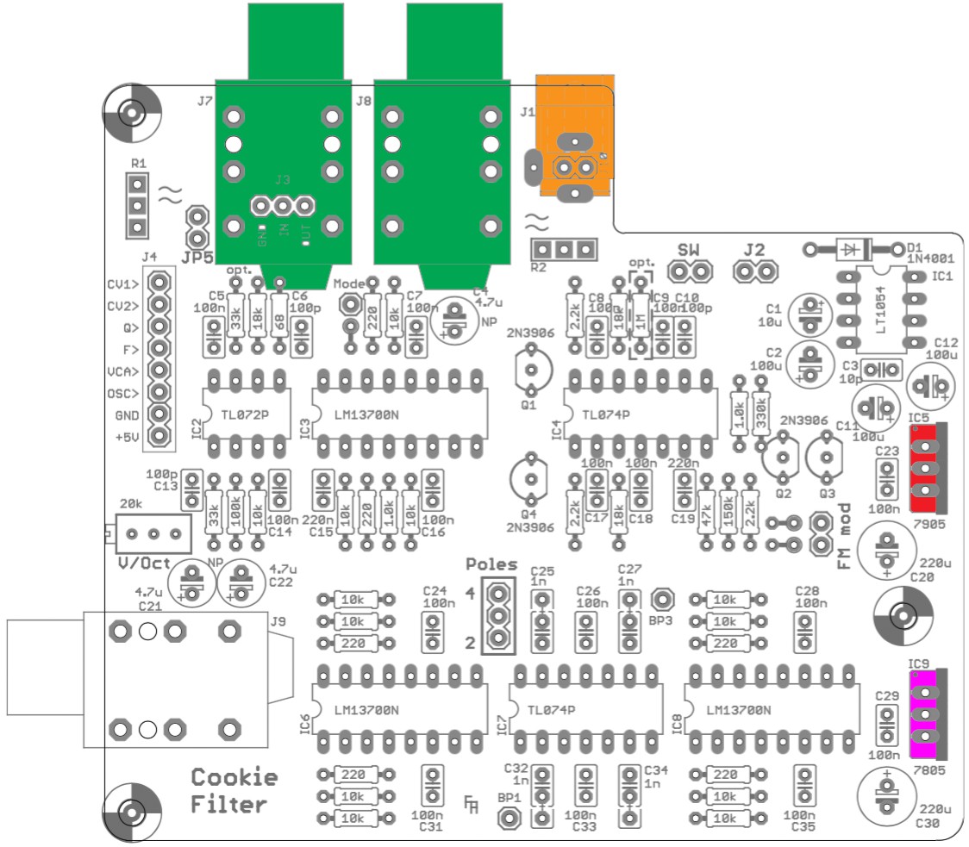
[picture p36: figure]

J7, J8
→ 6.3 mm-
| Klinkenbuchse

IC5
→ 7905
Orientierung!

IC9
→ 7805
Orientierung!

Cookie Synth – Filter Board | 25 Die folgenden Bau-

elemente werden
über kleine Kabel
mit dem Filter-
| Board verbunden.

SW
| → Wippenschalter

Poles
→ Kippschalter

R2
→ Potentiometer
10 kΩ
4,7 kΩ zwischen
Links und Mitte

Cookie Synth – Filter Board | 26
IC1 (LT1054)
einsetzen

9 V-Netzteil
anschließen
Polarität
beachten!

Spannung
messen:
| GND (Masse)

+5 Volt

-5 Volt

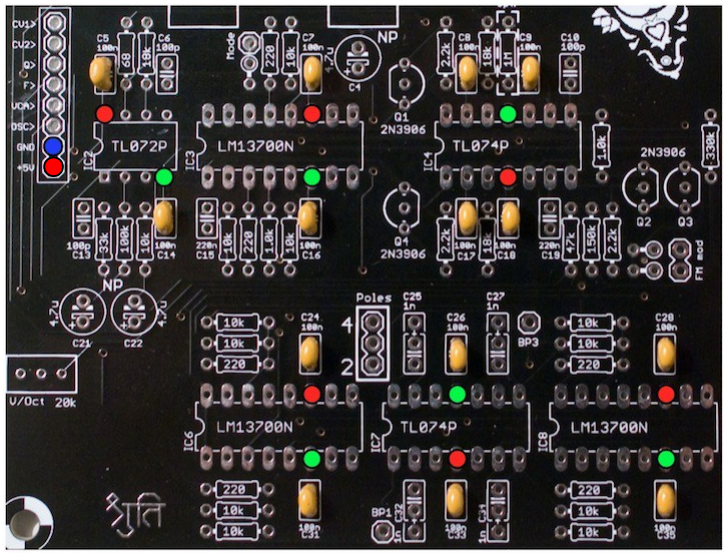
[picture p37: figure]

Alles OK?
→ dann die restlichen ICs einsetzen
Kerbe am IC muss mit der Kerbe im Sockel übereinstimmen!

Cookie Synth – Filter Board | 27
J4
→ Buchsenleiste

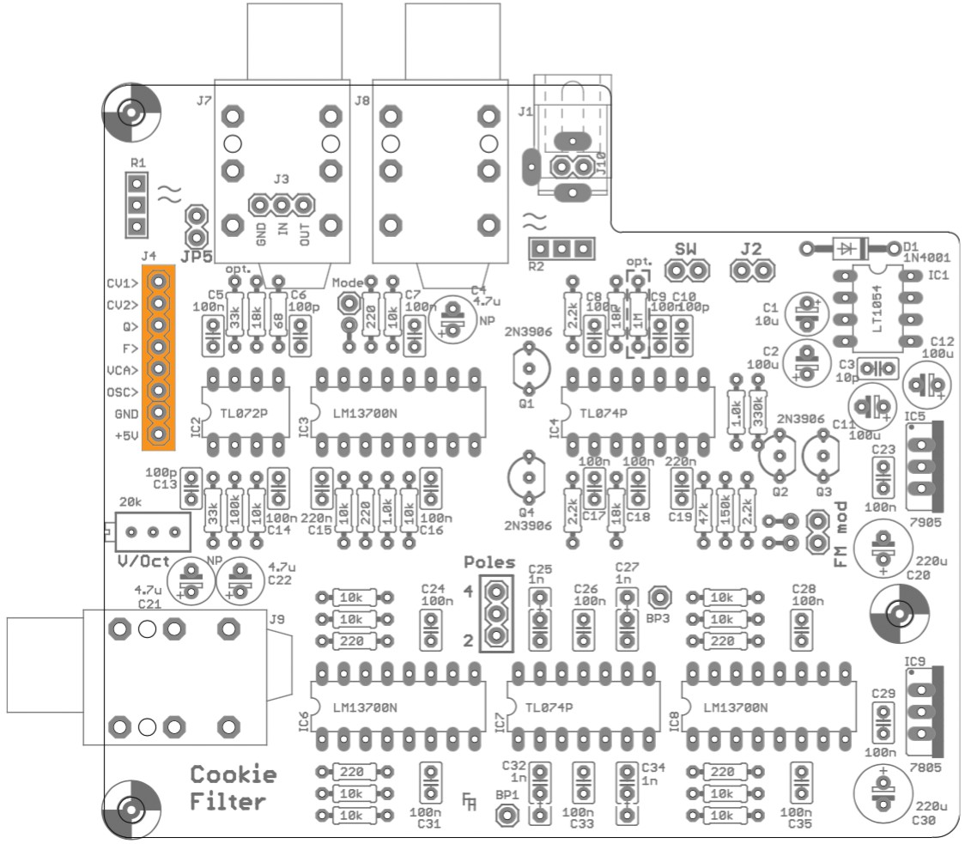
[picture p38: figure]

Vorgehensweise

1) Die Buchsenleiste auf
die Stiftleiste der
Controllerplatine
aufstecken.
2) Beide Platinen mit 20
mm-Distanzhülsen
| übereinander montieren.
3) Buchsenleiste auf
| dem Filterboard verlöten.

Cookie Synth – Filter Board | 28

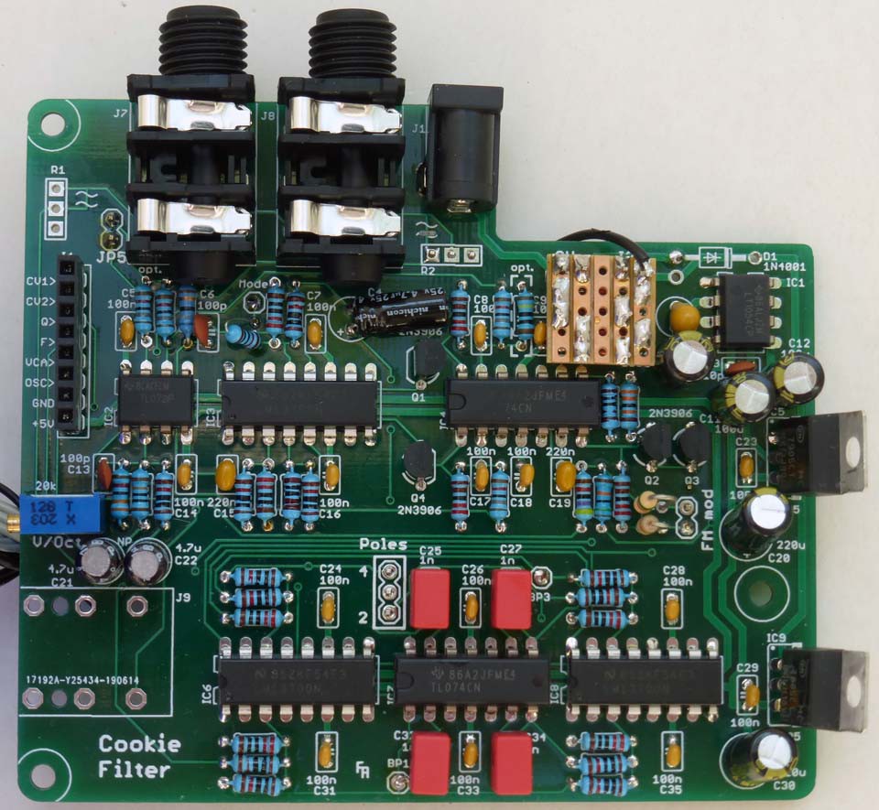
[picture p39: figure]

# Bravo!

# Wir sind kurz vor

dem Ziel.

Cookie Synth – Zusammenbau | 30

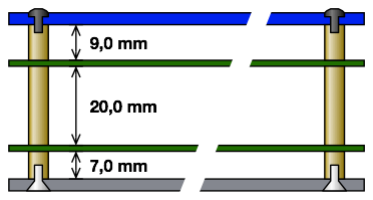
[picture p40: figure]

Schrauben „mit Gefühl“ anziehen, damit das Plexiglas nicht reißt / bricht.

Cookie Synth – Kalibration | 31

Ein Keyboard anschließen.

Am Cookie folgendes
einstellen:

Oscillator 1 shape: none
Oscillator 2 shape: none
Filter cutoff: 64
Filter resonance: 63
Filter envelope and LFO
modulations: 0

Auf dem Keyboard ein
Oktav-Intervall spielen
und den V/Oct-Trimmer
so verstellen, dass auch
eine Oktave zu hören ist.

# Herzlichen

# Glückwunsch!

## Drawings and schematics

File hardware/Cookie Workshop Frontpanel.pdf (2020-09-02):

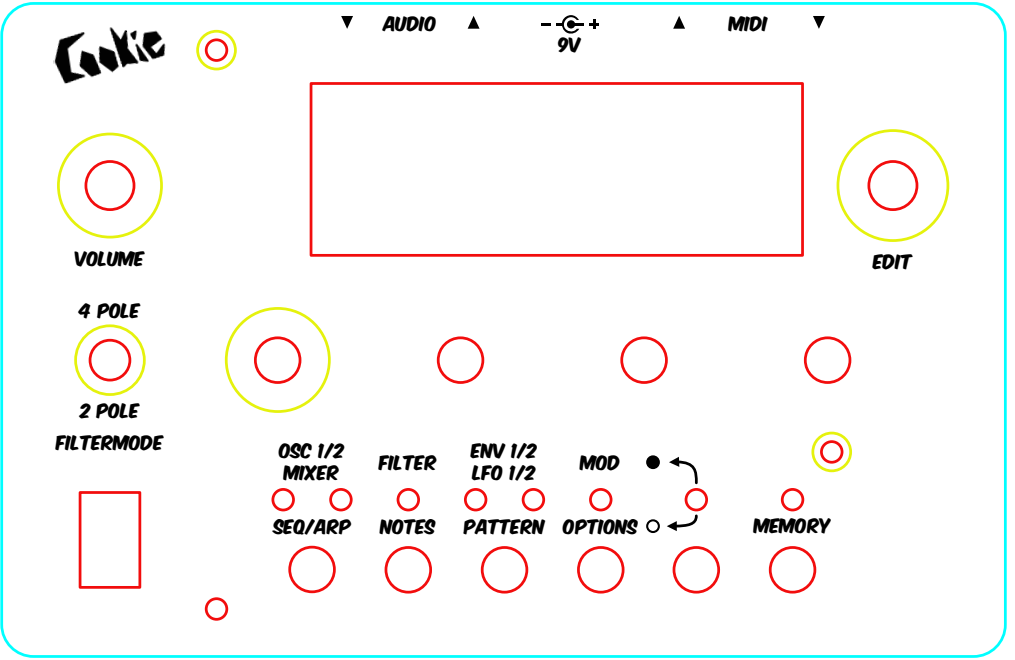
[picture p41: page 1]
VOLUME; FILTERMODE; OSC 1/2; MIXER; FILTER; MOD; MEMORY; EDIT; MIDI; AUDIO; SEQ/ARP; NOTES; PATTERN OPTIONS; ENV 1/2 LFO 1/2; 4 POLE; 2 POLE

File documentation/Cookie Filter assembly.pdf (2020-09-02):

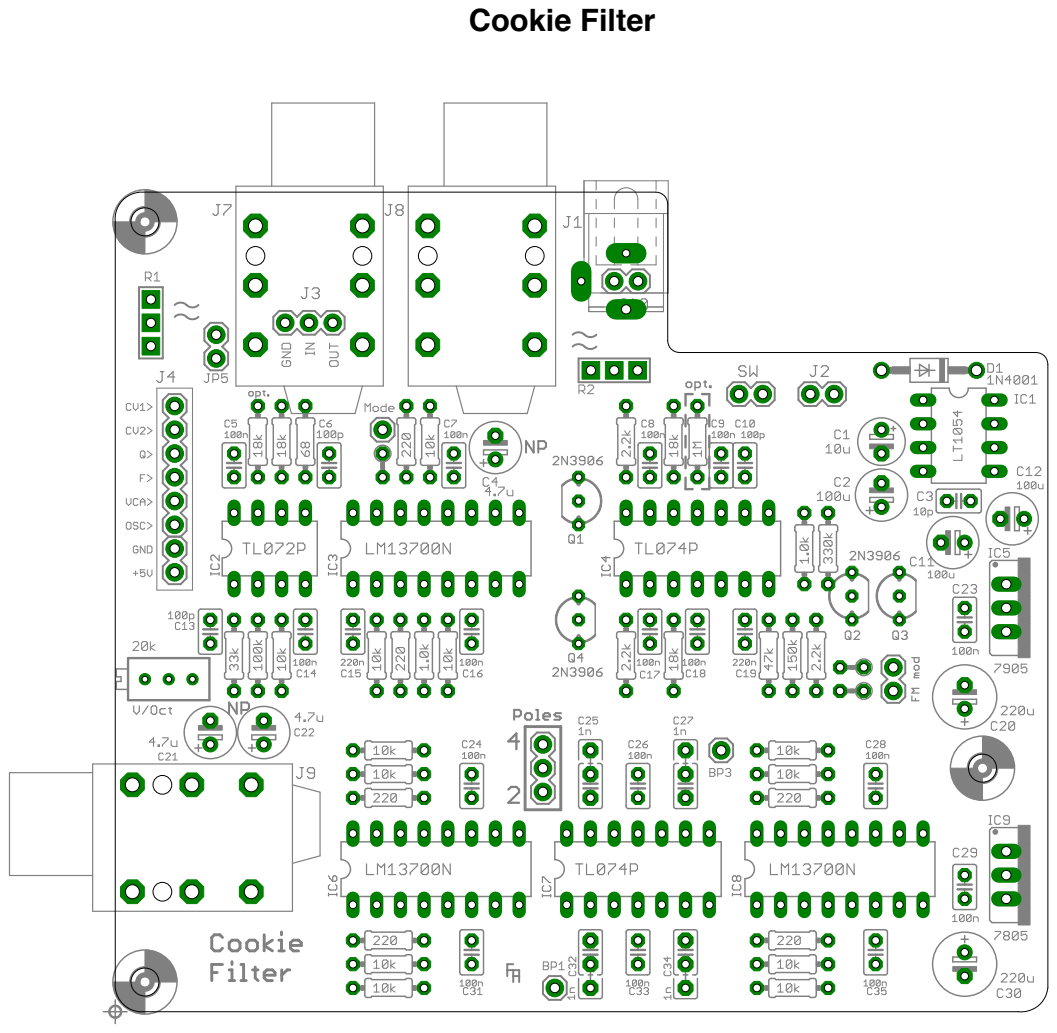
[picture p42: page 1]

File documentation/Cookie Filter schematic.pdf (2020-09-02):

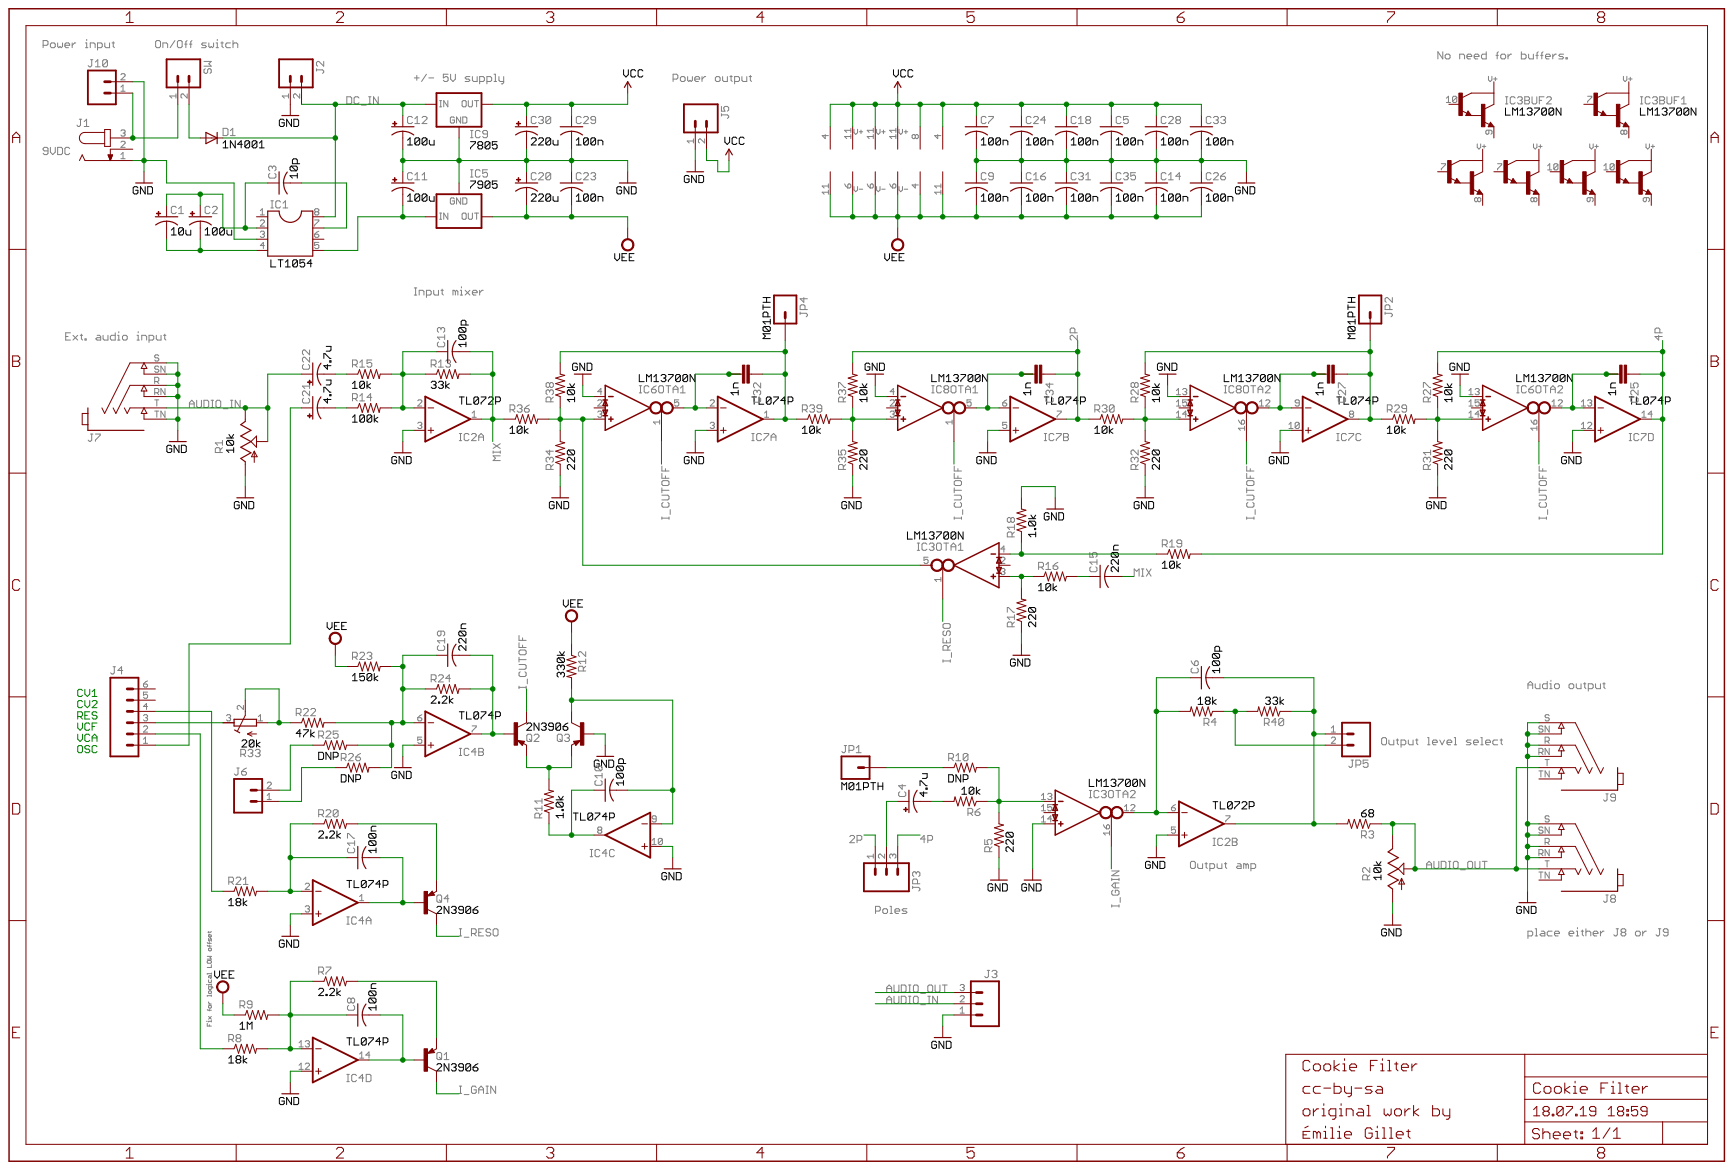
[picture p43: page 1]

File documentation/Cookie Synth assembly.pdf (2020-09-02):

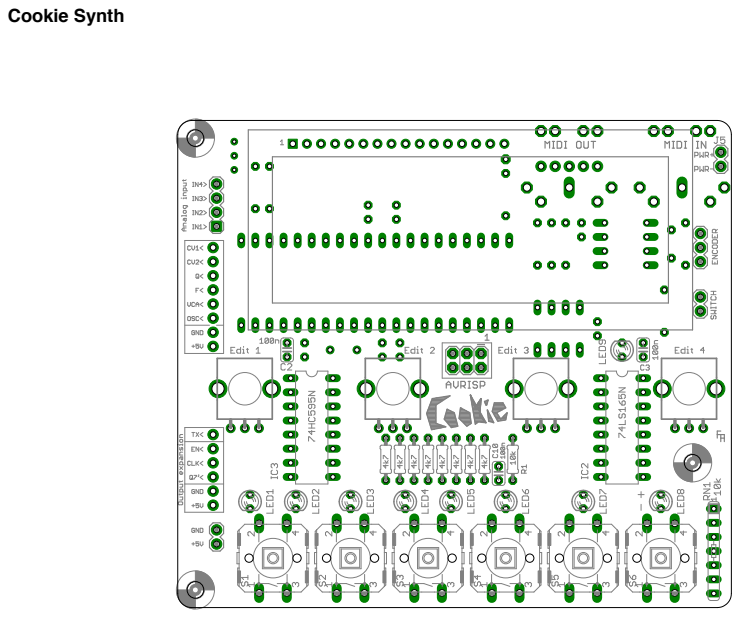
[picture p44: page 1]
Cookie Synth

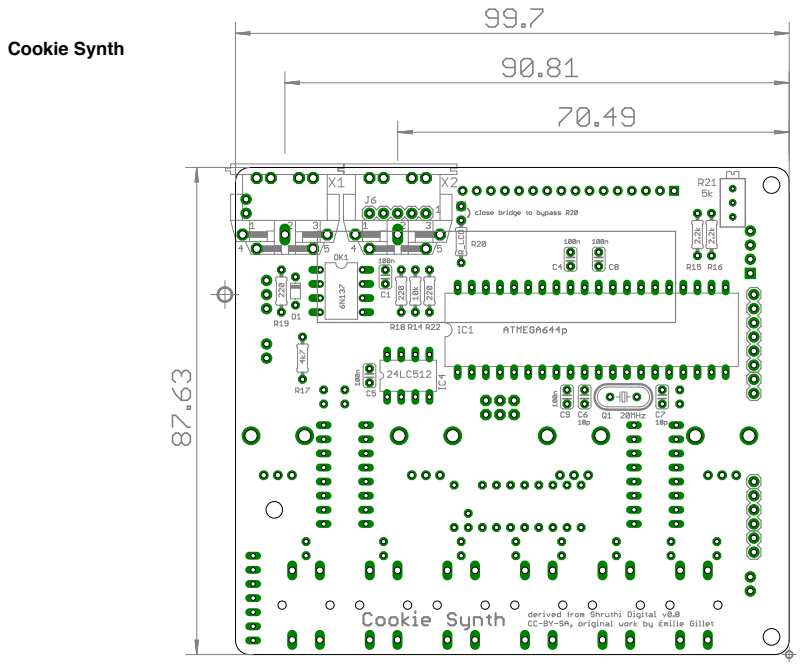
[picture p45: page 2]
Cookie Synth

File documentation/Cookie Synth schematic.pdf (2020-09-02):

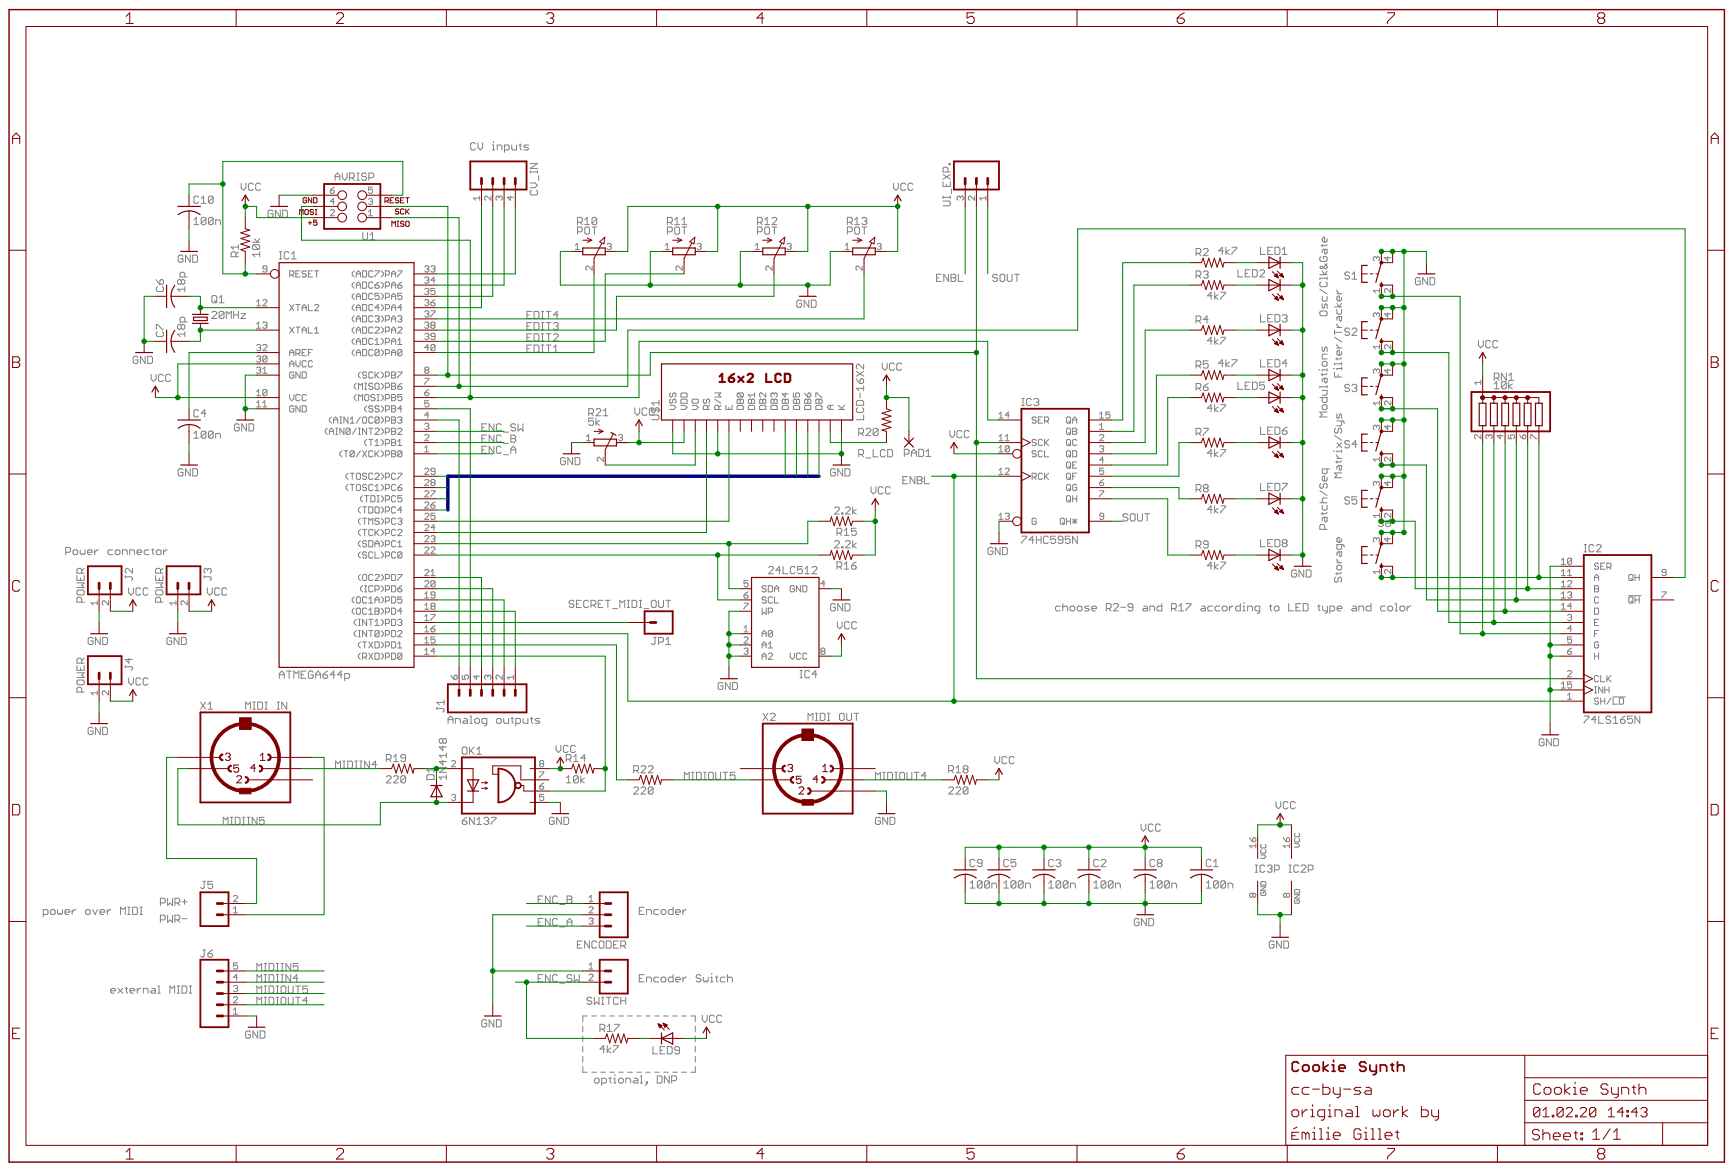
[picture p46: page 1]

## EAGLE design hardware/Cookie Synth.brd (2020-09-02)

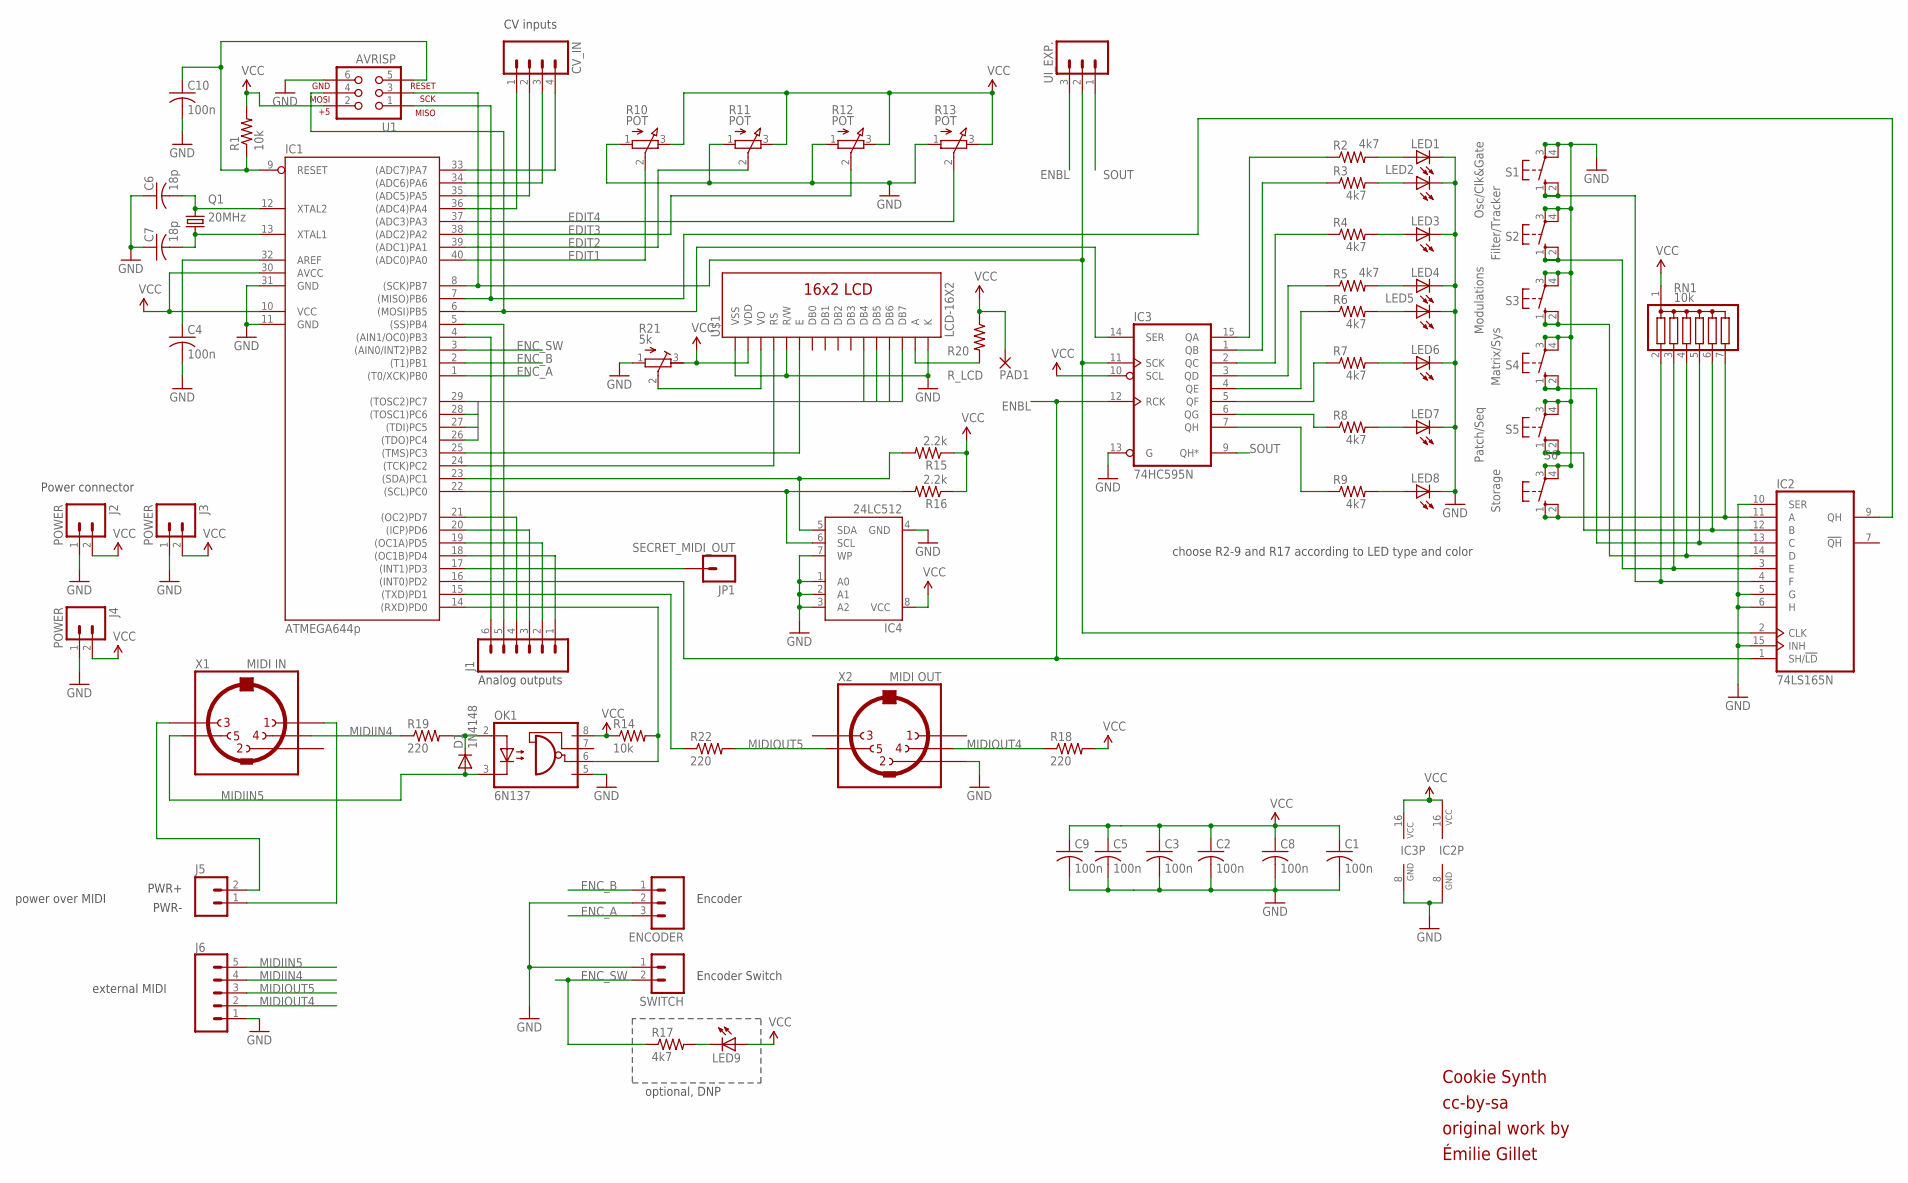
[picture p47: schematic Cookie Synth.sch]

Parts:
C1, C2, C3, C4, C5, C8, C9, C10: 100n; C025-024X044
C6, C7: 18p; C025-024X044
CV_IN: M04PTH; 1X04
D1: 1N4148; D-5
ENCODER: M03PTH; 1X03
IC1: ATMEGA644p; DIL40
IC2: 74LS165N; DIL16
IC3: 74HC595N; DIL16
IC4: 24LC512; DIL08
J1: M06SIP; 1X06
J2, J3, J4: POWER; 1X02
J5: M02PTH; 1X02
J6: CONN_05; 1X05
JP1: SECRET_MIDI_OUT; 1X01
LED1, LED2, LED3, LED4, LED5, LED6, LED7, LED8, LED9: LED3MM
OK1: 6N137; DIL08
PAD1: 1,6/0,8
Q1: 20MHz; HC49U-V
R1, R14: 10k; 0204/7
R2, R3, R4, R5, R6, R7, R8, R9, R17: 4k7; 0204/7
R10, R11, R12, R13: POT; POTI_ALPS_RK09
R15, R16: 2.2k; 0204/7
R18, R19, R22: 220; 0204/7
R20: R_LCD; 0204/7
R21: 5k; RTRIM3296X
RN1: 10k; SIL7
S1: Osc/Clk&Gate; B3F-40XX
S2: Filter/Tracker; B3F-40XX
S3: Modulations; B3F-40XX
S4: Matrix/Sys; B3F-40XX
S5: Patch/Seq; B3F-40XX
S6: Storage; B3F-40XX
SWITCH: M02PTH; 1X02
U1: AVRISP; 2X3
U$1: LCD-16X2
UI_EXP.: M03PTH; 1X03
X1: MIDI IN; MAB5SH
X2: MIDI OUT; MAB5SH

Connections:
EDIT1: IC1.40 ((ADC0)PA0), R10.2 (S)
EDIT2: IC1.39 ((ADC1)PA1), R11.2 (S)
EDIT3: IC1.38 ((ADC2)PA2), R12.2 (S)
EDIT4: IC1.37 ((ADC3)PA3), R13.2 (S)
ENBL: IC1.16 ((INT0)PD2), IC2.1 (SH/!LD), IC3.12 (RCK), UI_EXP..3
ENC_A: ENCODER.3, IC1.1 ((T0/XCK)PB0)
ENC_B: ENCODER.1, IC1.2 ((T1)PB1)
ENC_SW: IC1.3 ((AIN0/INT2)PB2), R17.1, SWITCH.2
GND: C1.2, C2.2, C3.2, C4.2, C5.2, C6.1, C7.1, C8.2, C9.2, C10.2, ENCODER.2, IC1.11 (GND), IC1.31 (GND), IC2.5 (G), IC2.6 (H), IC2.8 (GND), IC2.10 (SER), IC2.15 (INH), IC3.8 (GND), IC3.13 (G), IC4.1 (A0), IC4.2 (A1), IC4.3 (A2), IC4.4 (GND), IC4.7 (WP), J2.1, J3.1, J4.1, J6.1, LED1.K (C), LED2.K (C), LED3.K (C), LED4.K (C), LED5.K (C), LED6.K (C), LED7.K (C), LED8.K (C), OK1.5 (GND), R10.1 (A), R11.1 (A), R12.1 (A), R13.1 (A), R21.1 (E), S1.3, S1.4 (P1), S2.3, S2.4 (P1), S3.3, S3.4 (P1), S4.3, S4.4 (P1), S5.3, S5.4 (P1), S6.3, S6.4 (P1), SWITCH.1, U1.6, U$1.1 (VSS), U$1.5 (R/W), U$1.16 (K), X2.2
LCD_DATA1: IC1.26 ((TDO)PC4), U$1.11 (DB4)
LCD_DATA2: IC1.27 ((TDI)PC5), U$1.12 (DB5)
LCD_DATA3: IC1.28 ((TOSC1)PC6), U$1.13 (DB6)
LCD_DATA4: IC1.29 ((TOSC2)PC7), U$1.14 (DB7)
MIDIIN4: J6.4, R19.1, X1.4
MIDIIN5: D1.A, J6.5, OK1.3 (C), X1.5
MIDIOUT4: J6.2, R18.1, X2.4
MIDIOUT5: J6.3, R22.2, X2.5
unnamed: IC3.2 (QC), R4.1
unnamed: IC1.24 ((TCK)PC2), U$1.4 (RS)
unnamed: IC2.11 (A), RN1.7, S6.1 (S), S6.2 (S1)
unnamed: LED9.K (C), R17.2
unnamed: IC2.3 (E), RN1.3, S2.1 (S), S2.2 (S1)
unnamed: C10.1, IC1.9 (RESET), R1.1, U1.5
unnamed: C4.1, IC1.32 (AREF)
unnamed: IC1.8 ((SCK)PB7), IC2.2 (CLK), IC3.11 (SCK), U1.3, UI_EXP..2
unnamed: IC1.7 ((MISO)PB6), IC2.9 (QH), U1.1
unnamed: CV_IN.1, IC1.36 ((ADC4)PA4)
unnamed: CV_IN.2, IC1.35 ((ADC5)PA5)
unnamed: CV_IN.3, IC1.34 ((ADC6)PA6)
unnamed: CV_IN.4, IC1.33 ((ADC7)PA7)
unnamed: R20.2, U$1.15 (A)
unnamed: IC1.4 ((AIN1/OC0)PB3), J1.6
unnamed: IC1.5 ((SS)PB4), J1.5
unnamed: IC1.18 ((OC1B)PD4), J1.1
unnamed: IC1.19 ((OC1A)PD5), J1.2
unnamed: IC1.20 ((ICP)PD6), J1.3
unnamed: IC1.21 ((OC2)PD7), J1.4
unnamed: J5.1, X1.1
unnamed: IC1.17 ((INT1)PD3), JP1.1
unnamed: IC1.23 ((SDA)PC1), IC4.5 (SDA), R15.2
unnamed: D1.C, OK1.2 (A), R19.2
unnamed: J5.2, X1.3
unnamed: IC3.15 (QA), R2.1
unnamed: IC3.1 (QB), R3.1
unnamed: IC1.22 ((SCL)PC0), IC4.6 (SCL), R16.2
unnamed: IC3.3 (QD), R5.1
unnamed: IC3.4 (QE), R6.1
unnamed: IC3.5 (QF), R7.1
unnamed: IC3.7 (QH), R9.1
unnamed: IC3.6 (QG), R8.1
unnamed: LED1.A, R2.2
unnamed: LED2.A, R3.2
unnamed: LED3.A, R4.2
unnamed: LED4.A, R5.2
unnamed: LED5.A, R6.2
unnamed: LED6.A, R7.2
unnamed: LED7.A, R8.2
unnamed: LED8.A, R9.2
unnamed: IC1.6 ((MOSI)PB5), IC3.14 (SER), U1.4
unnamed: IC2.4 (F), RN1.2, S1.1 (S), S1.2 (S1)
unnamed: IC2.14 (D), RN1.4, S3.1 (S), S3.2 (S1)
unnamed: IC2.13 (C), RN1.5, S4.1 (S), S4.2 (S1)
unnamed: IC2.12 (B), RN1.6, S5.1 (S), S5.2 (S1)
unnamed: IC1.25 ((TMS)PC3), U$1.6 (E)
unnamed: R21.2 (S), U$1.3 (VO)
unnamed: C7.2, IC1.13 (XTAL1), Q1.1
unnamed: C6.2, IC1.12 (XTAL2), Q1.2
RXD: IC1.14 ((RXD)PD0), OK1.6 (VO), R14.2
SOUT: IC3.9 (QH*), UI_EXP..1
TXD: IC1.15 ((TXD)PD1), R22.1
VCC: C1.1, C2.1, C3.1, C5.1, C8.1, C9.1, IC1.10 (VCC), IC1.30 (AVCC), IC2.16 (VCC), IC3.10 (SCL), IC3.16 (VCC), IC4.8 (VCC), J2.2, J3.2, J4.2, LED9.A, OK1.8 (VCC), PAD1.1, R1.2, R10.3 (E), R11.3 (E), R12.3 (E), R13.3 (E), R14.1, R15.1, R16.1, R18.2, R20.1, R21.3 (A), RN1.1, U1.2, U$1.2 (VDD)

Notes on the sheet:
CV inputs
Power connector
Analog outputs
cc-by-sa
original work by
PWR-
PWR+
Encoder
Encoder Switch
Émilie Gillet
Cookie Synth
external MIDI
power over MIDI
optional, DNP
choose R2-9 and R17 according to LED type and color

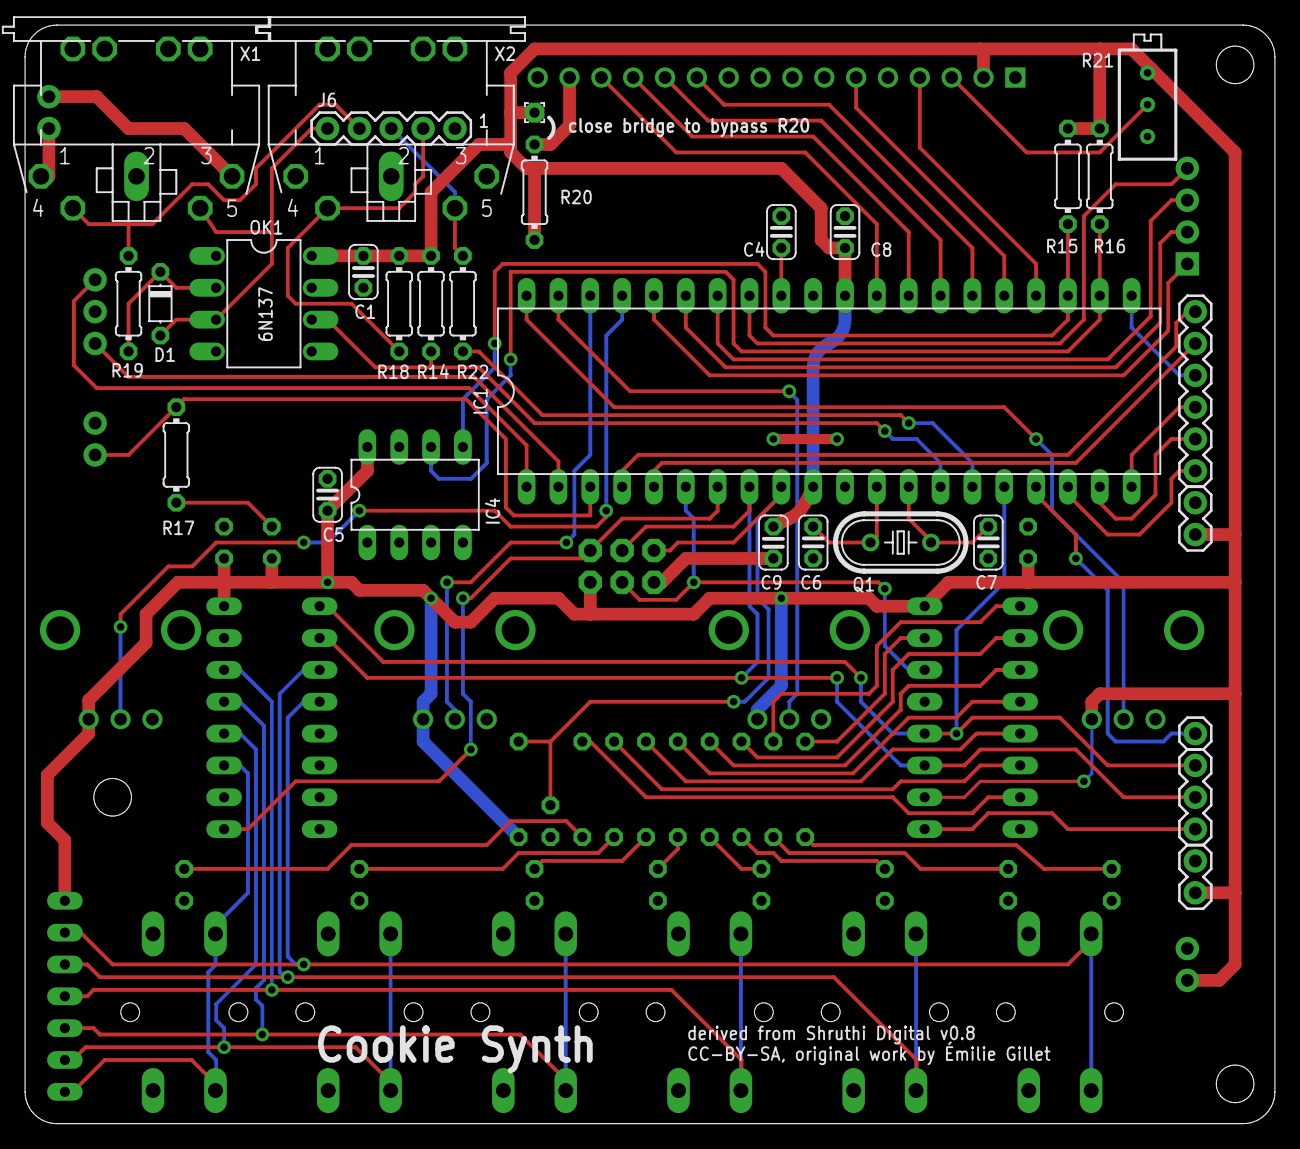
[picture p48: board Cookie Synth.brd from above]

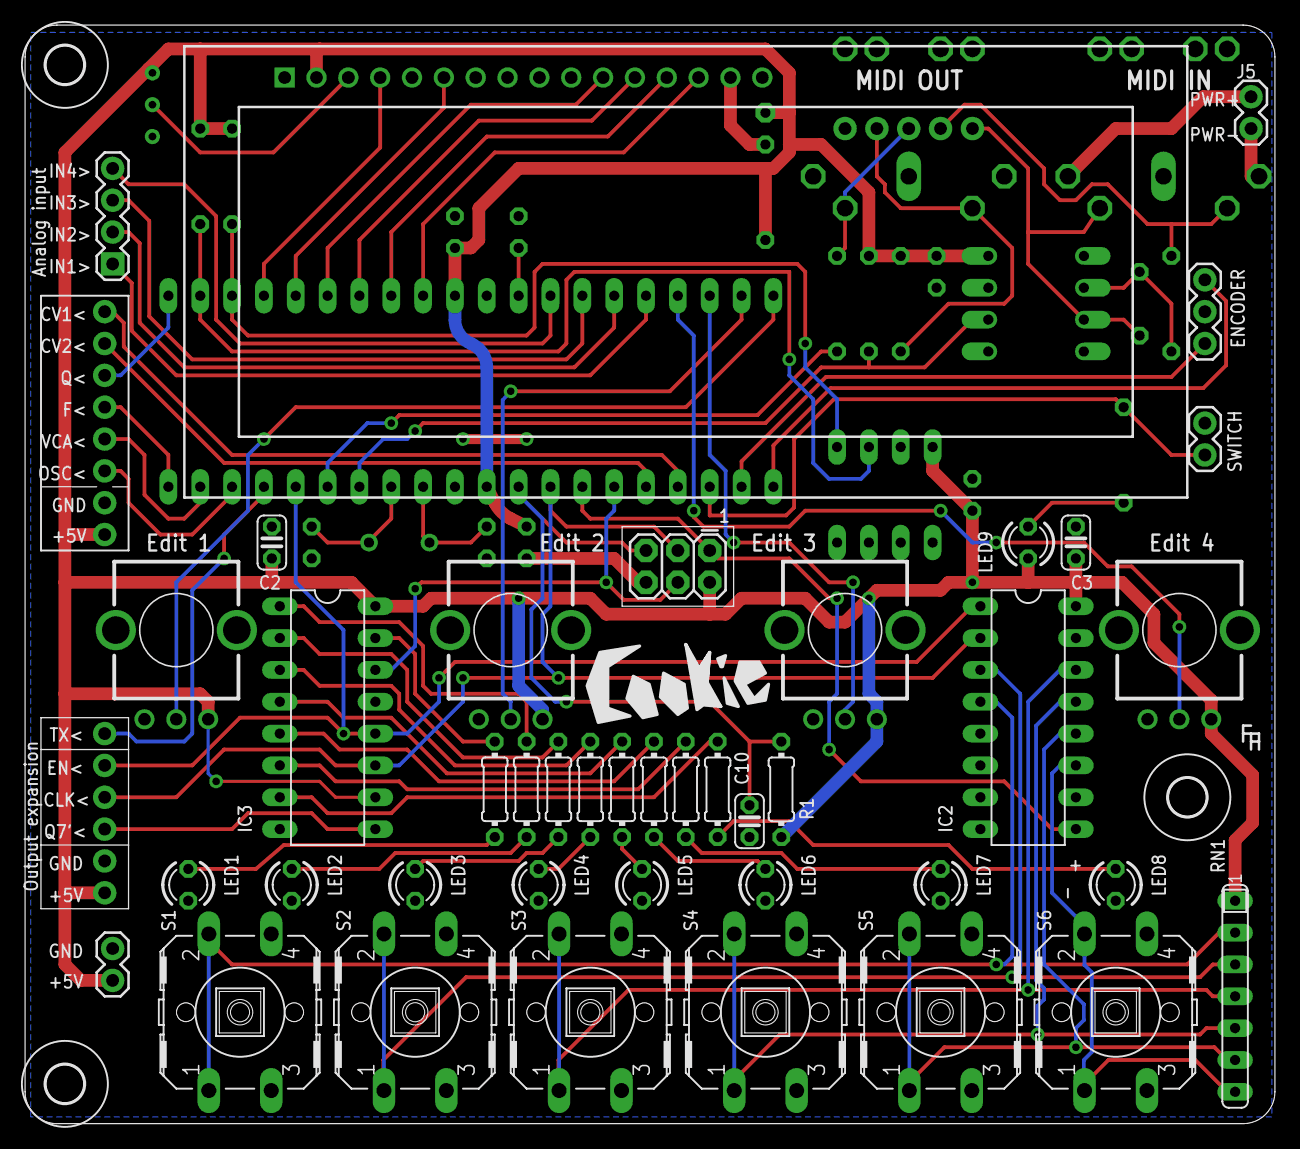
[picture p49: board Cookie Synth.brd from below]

Board: 2 copper layers, 99.7 x 87.6 mm, 74 parts (44 on the bottom side), 71 nets.

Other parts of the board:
U$2, U$3, U$4: 3,0

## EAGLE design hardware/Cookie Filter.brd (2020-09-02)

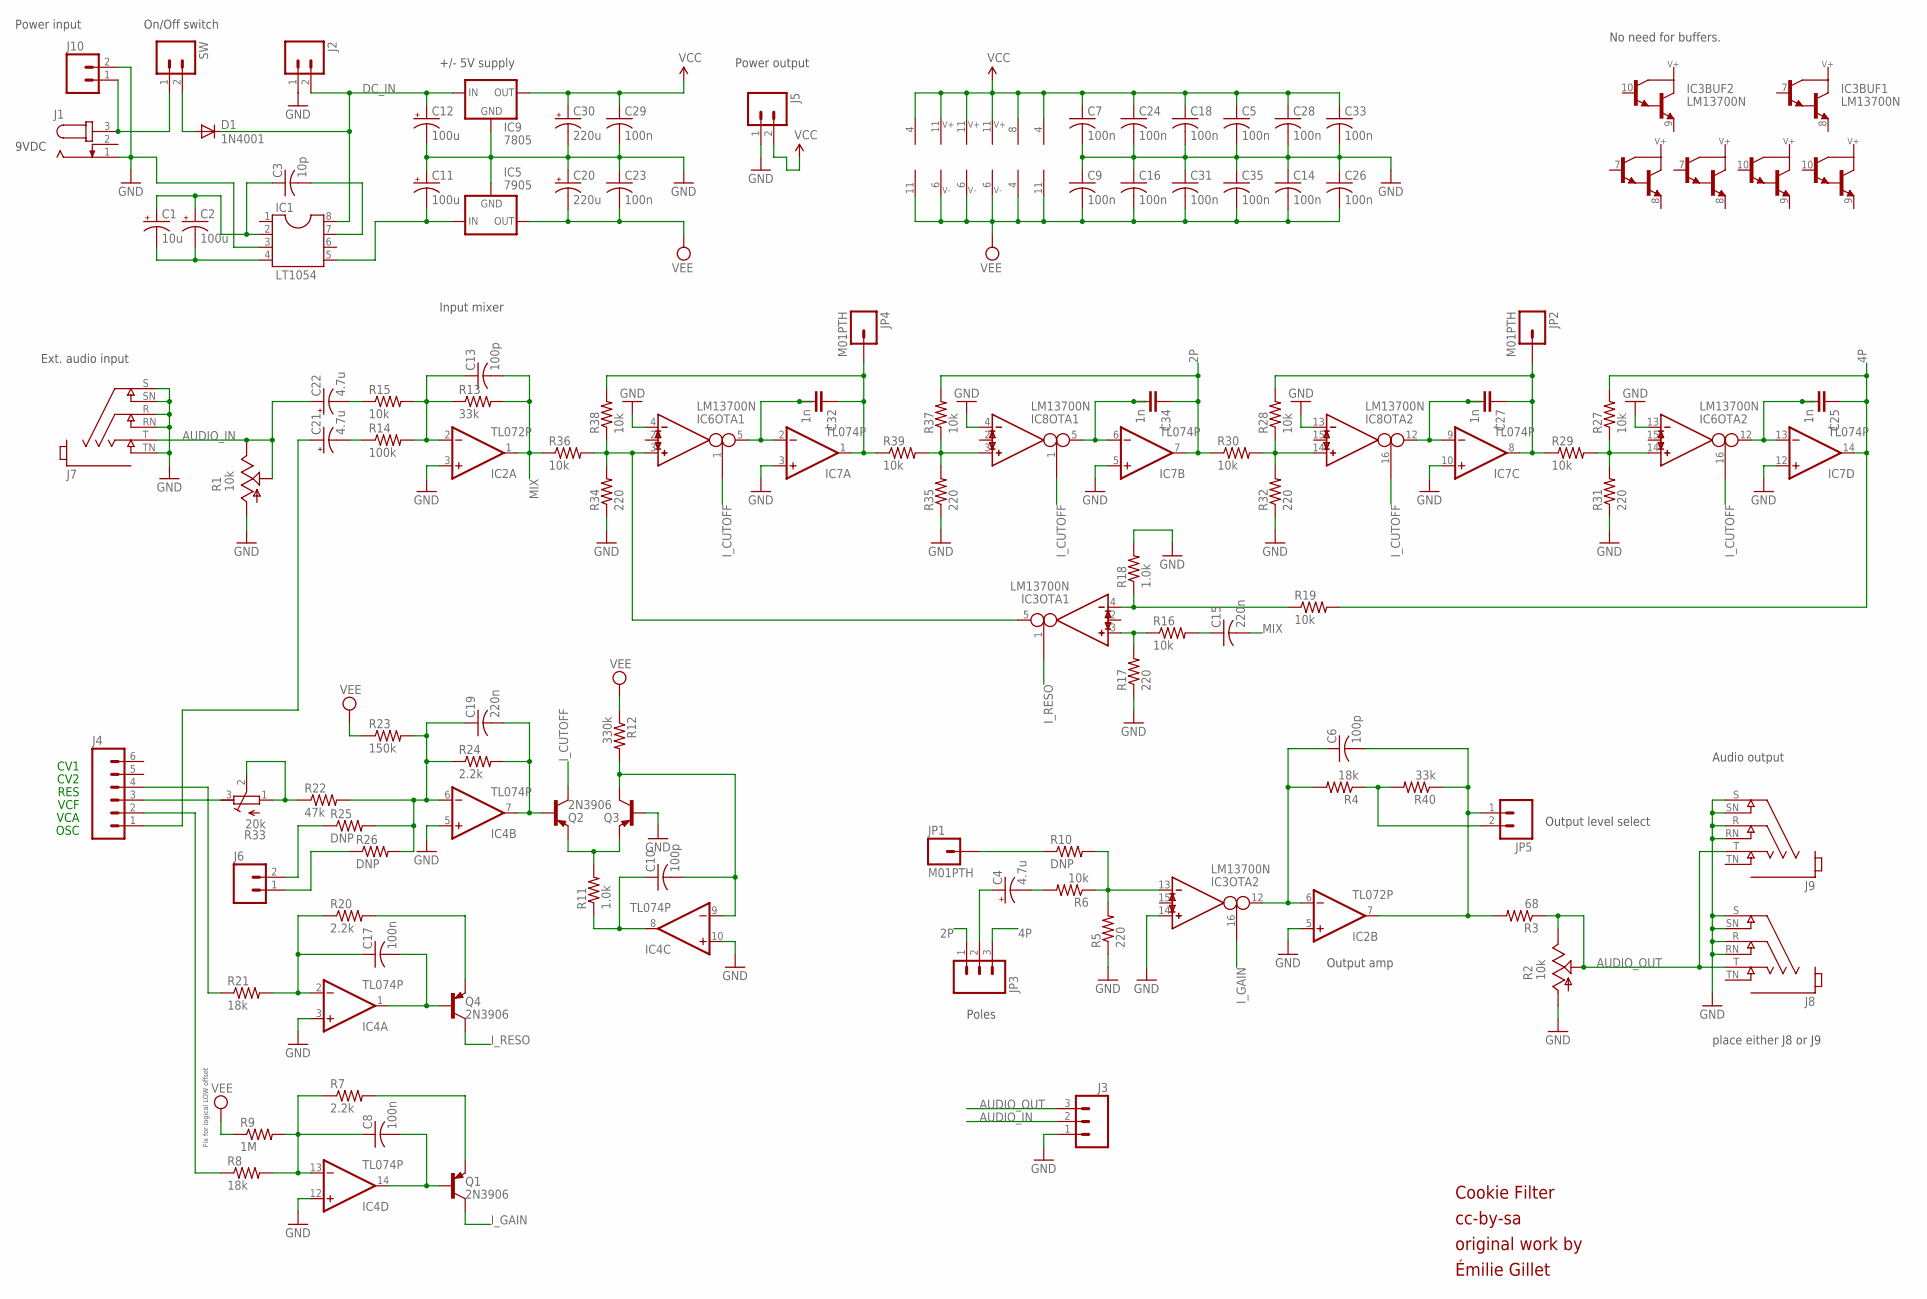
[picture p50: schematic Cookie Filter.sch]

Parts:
C1: 10u; E2,5-5
C2, C11, C12: 100u; E2,5-6
C3: 10p; C025-025X050
C4, C21, C22: 4.7u; E2,5-6
C5, C7, C8, C9, C14, C16, C17, C18, C23, C24, C26, C28, C29, C31, C33, C35: 100n; C025-025X050
C6, C10, C13: 100p; C025-025X050
C15, C19: 220n; C025-025X050
C20, C30: 220u; E2,5-7
C25, C27, C32, C34: 1n; C2.5/5-2
D1: 1N4001; DO41-10
IC1: LT1054; DIL08
IC2: TL072P; DIL08
IC3, IC6, IC8: LM13700N; DIL16
IC4, IC7: TL074P; DIL14
IC5: 7905; 79XXS
IC9: 7805; 78XXS
J1: JACK-PLUG1; SPC4078
J2, J5, J6, J10: M02PTH; 1X02
J3: M03PTH; 1X03
J4: M06SIP; 1X06
J7, J8, J9: NRJ4HF; NRJ6HF
JP1, JP2, JP4: M01PTH; 1X01
JP3: M03PTH; 1X03
JP5: M02PTH; 1X02
Q1, Q2, Q3, Q4: 2N3906; TO92-
R1, R2: 10k; CABLE_POT_6MM
R3: 68; 0204/7
R4, R8, R21: 18k; 0204/7
R5, R17, R31, R32, R34, R35: 220; 0204/7
R6, R15, R16, R19, R27, R28, R29, R30, R36, R37, R38, R39: 10k; 0204/7
R7, R20, R24: 2.2k; 0204/7
R9: 1M; 0204/7
R10, R25, R26: DNP; 0204V
R11, R18: 1.0k; 0204/7
R12: 330k; 0204/7
R13, R40: 33k; 0204/7
R14: 100k; 0204/7
R22: 47k; 0204/7
R23: 150k; 0204/7
R33: 20k; RTRIM3296X
SW: M02PTH; 1X02

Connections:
2P: C34.1, IC7.7 (OUT), JP3.1, R30.1, R37.2
4P: C25.1, IC7.14 (OUT), JP3.3, R19.2, R27.2
AUDIO_IN: C22.+, J3.2, J7.T, R1.E, R1.S
AUDIO_OUT: J3.3, J8.T, J9.T, R2.E, R2.S, R3.1
DC_IN: C12.+, D1.C, IC1.8, IC9.IN, J2.2
DC_NEG: C11.-, IC1.5, IC5.IN
GND: C5.2, C7.2, C9.1, C11.+, C12.-, C14.1, C16.1, C18.2, C20.+, C23.1, C24.2, C26.1, C28.2, C29.2, C30.-, C31.1, C33.2, C35.1, IC1.3, IC2.3 (+IN), IC2.5 (+IN), IC3.14 (IN_P), IC4.3 (+IN), IC4.5 (+IN), IC4.10 (+IN), IC4.12 (+IN), IC5.GND, IC6.4 (IN_N), IC6.13 (IN_N), IC7.3 (+IN), IC7.5 (+IN), IC7.10 (+IN), IC7.12 (+IN), IC8.4 (IN_N), IC8.13 (IN_N), IC9.GND, J1.1, J2.1, J3.1, J5.1, J7.R, J7.RN, J7.S, J7.SN, J7.TN, J8.R, J8.RN, J8.S, J8.SN, J9.R, J9.RN, J9.S, J9.SN, J10.2, Q3.2 (B), R1.A, R2.A, R5.1, R17.1, R18.2, R31.1, R32.1, R34.1, R35.1
I_CUTOFF: IC6.1 (I_BIAS), IC6.16 (I_BIAS), IC8.1 (I_BIAS), IC8.16 (I_BIAS), Q2.1 (C)
I_GAIN: IC3.16 (I_BIAS), Q1.1 (C)
I_RESO: IC3.1 (I_BIAS), Q4.1 (C)
MIX: C13.2, C15.2, IC2.1 (OUT), R13.2, R36.1
unnamed: JP1.1, R10.1
unnamed: C19.2, IC4.7 (OUT), Q2.2 (B), R24.2
unnamed: R22.1, R33.1 (E), R33.2 (S)
unnamed: J4.3, R33.3 (A)
unnamed: JP5.2, R4.1, R40.2
unnamed: C13.1, IC2.2 (-IN), R13.1, R14.2, R15.2
unnamed: Q2.3 (E), Q3.3 (E), R11.2
unnamed: C4.+, JP3.2
unnamed: C10.1, IC4.8 (OUT), R11.1
unnamed: C10.2, IC4.9 (-IN), Q3.1 (C), R12.2
unnamed: J4.4, R21.1
unnamed: IC3.5 (OUT), IC6.3 (IN_P), R34.2, R36.2, R38.1
unnamed: J1.3, J10.1, SW.1
unnamed: C32.1, IC7.1 (OUT), JP4.1, R38.2, R39.1
unnamed: IC8.3 (IN_P), R35.2, R37.1, R39.2
unnamed: C4.-, R6.2
unnamed: J6.2, R25.1
unnamed: IC8.14 (IN_P), R28.1, R30.2, R32.2
unnamed: C15.1, R16.2
unnamed: J6.1, R26.1
unnamed: IC6.14 (IN_P), R27.1, R29.2, R31.2
unnamed: C27.1, IC7.8 (OUT), JP2.1, R28.2, R29.1
unnamed: C32.2, C32.3, IC6.5 (OUT), IC7.2 (-IN)
unnamed: C34.2, C34.3, IC7.6 (-IN), IC8.5 (OUT)
unnamed: IC3.4 (IN_N), R18.1, R19.1
unnamed: C17.2, IC4.1 (OUT), Q4.2 (B)
unnamed: C8.2, IC4.14 (OUT), Q1.2 (B)
unnamed: IC3.3 (IN_P), R16.1, R17.2
unnamed: IC3.13 (IN_N), R5.2, R6.1, R10.2
unnamed: C21.+, J4.1
unnamed: C27.2, C27.3, IC7.9 (-IN), IC8.12 (OUT)
unnamed: C25.2, C25.3, IC6.12 (OUT), IC7.13 (-IN)
unnamed: C21.-, R14.1
unnamed: C19.1, IC4.6 (-IN), R22.2, R23.2, R24.1, R25.2, R26.2
unnamed: J4.2, R8.1
unnamed: C1.+, C2.+, C3.1, IC1.2
unnamed: C1.-, C2.-, IC1.4
unnamed: C3.2, IC1.7
unnamed: C8.1, IC4.13 (-IN), R7.1, R8.2, R9.2
unnamed: C17.1, IC4.2 (-IN), R20.1, R21.2
unnamed: D1.A, SW.2
unnamed: Q4.3 (E), R20.2
unnamed: C6.2, IC2.7 (OUT), JP5.1, R3.2, R40.1
unnamed: Q1.3 (E), R7.2
unnamed: C6.1, IC2.6 (-IN), IC3.12 (OUT), R4.2
unnamed: C22.-, R15.1
VCC: C5.1, C7.1, C18.1, C24.1, C28.1, C29.1, C30.+, C33.1, IC2.8 (V+), IC3.11 (V+), IC4.4 (V+), IC6.11 (V+), IC7.4 (V+), IC8.11 (V+), IC9.OUT, J5.2
VEE: C9.2, C14.2, C16.2, C20.-, C23.2, C26.2, C31.2, C35.2, IC2.4 (V-), IC3.6 (V-), IC4.11 (V-), IC5.OUT, IC6.6 (V-), IC7.11 (V-), IC8.6 (V-), R9.1, R12.1, R23.1

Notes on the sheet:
Power output
OSC
VCA
VCF
RES
original work by
Output amp
CV1
CV2
Input mixer
+/- 5V supply
No need for buffers.
Fix for logical LOW offset
Émilie Gillet
Ext. audio input
cc-by-sa
Cookie Filter
Audio output
Power input
Poles
Output level select
9VDC
On/Off switch
place either J8 or J9

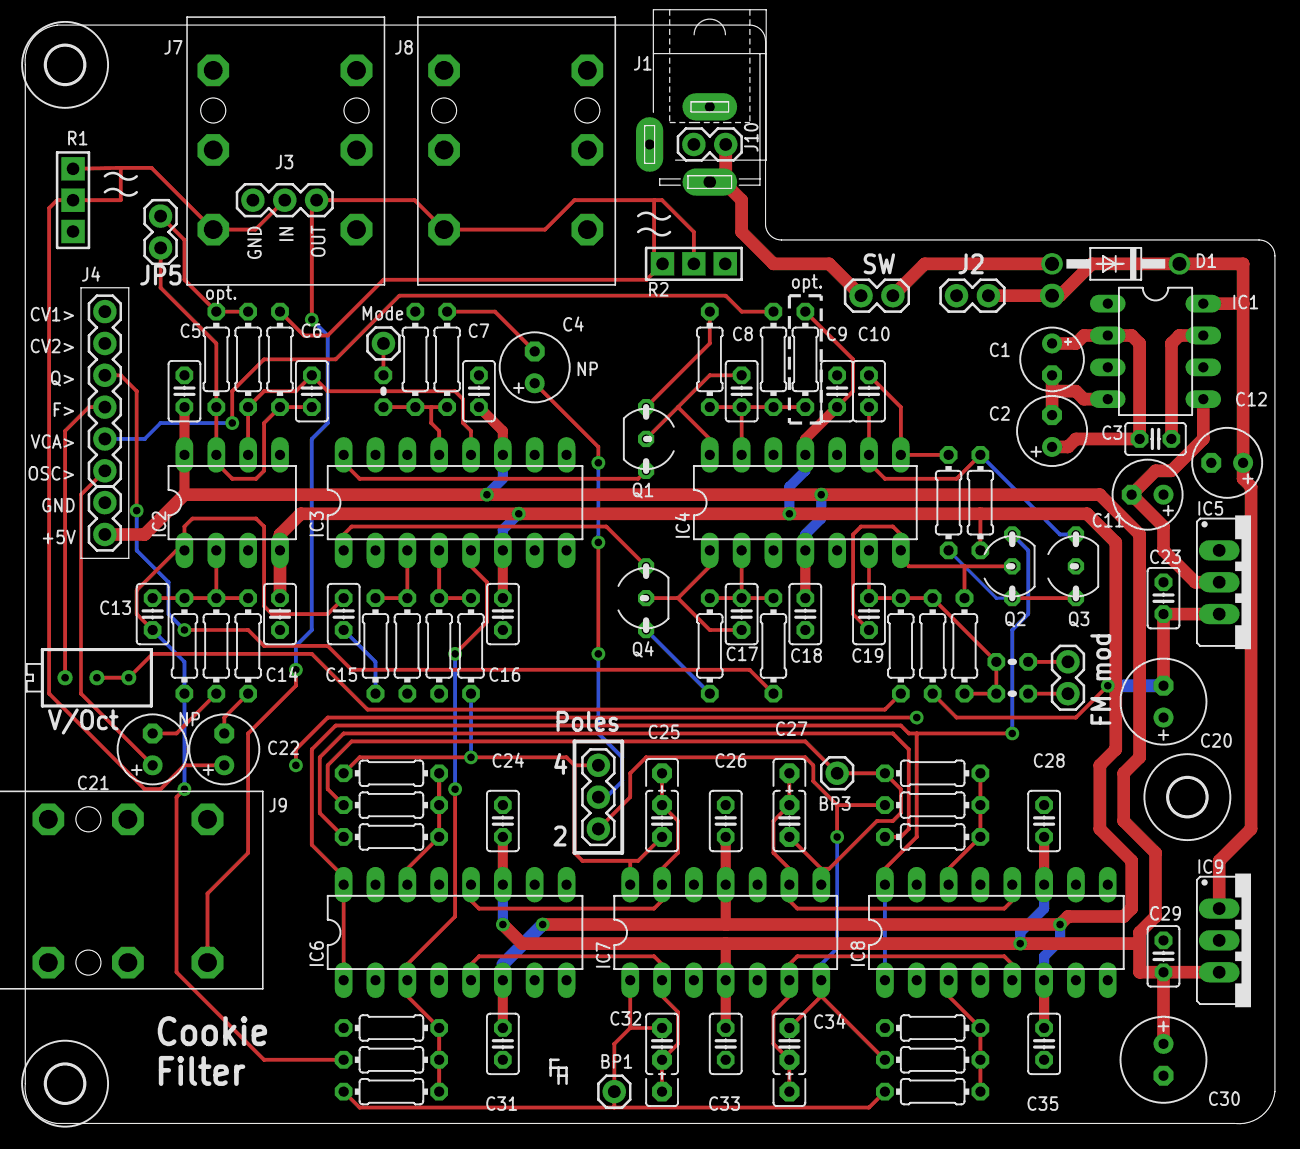
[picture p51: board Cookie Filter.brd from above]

Board: 2 copper layers, 99.7 x 87.6 mm, 108 parts (0 on the bottom side), 59 nets.

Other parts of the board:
U$1, U$4, U$5: 3,0

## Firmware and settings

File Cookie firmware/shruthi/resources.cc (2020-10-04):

// Copyright 2009 Olivier Gillet.
//
// Author: Olivier Gillet (ol.gillet@gmail.com)
//
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
// -----------------------------------------------------------------------------
//
// Resources definitions.
//
// Automatically generated with:
// make resources


#include "shruthi/resources.h"

namespace shruthi {

static const prog_char str_res_shape[] PROGMEM = "shape";
static const prog_char str_res_parameter[] PROGMEM = "parameter";
static const prog_char str_res_resonance[] PROGMEM = "resonance";
static const prog_char str_res_prm[] PROGMEM = "prm";
static const prog_char str_res_range[] PROGMEM = "range";
static const prog_char str_res_rng[] PROGMEM = "rng";
static const prog_char str_res_op_[] PROGMEM = "op.";
static const prog_char str_res_operator[] PROGMEM = "operator";
static const prog_char str_res_detune[] PROGMEM = "detune";
static const prog_char str_res_osc_mix[] PROGMEM = "osc mix";
static const prog_char str_res_sub_osc_[] PROGMEM = "sub osc.";
static const prog_char str_res_env1Tvcf[] PROGMEM = "env1~vcf";
static const prog_char str_res_lfo2Tvcf[] PROGMEM = "lfo2~vcf";
static const prog_char str_res_attack[] PROGMEM = "attack";
static const prog_char str_res_atk[] PROGMEM = "atk";
static const prog_char str_res_decay[] PROGMEM = "decay";
static const prog_char str_res_sustain[] PROGMEM = "sustain";
static const prog_char str_res_release[] PROGMEM = "release";
static const prog_char str_res_rate[] PROGMEM = "rate";
static const prog_char str_res_modulation[] PROGMEM = "modulation";
static const prog_char str_res_operators[] PROGMEM = "operators";
static const prog_char str_res_mod_[] PROGMEM = "mod.";
static const prog_char str_res_source[] PROGMEM = "source";
static const prog_char str_res_src[] PROGMEM = "src";
static const prog_char str_res_dest_[] PROGMEM = "dest.";
static const prog_char str_res_dst[] PROGMEM = "dst";
static const prog_char str_res_amount[] PROGMEM = "amount";
static const prog_char str_res_amt[] PROGMEM = "amt";
static const prog_char str_res_mode[] PROGMEM = "mode";
static const prog_char str_res_overdrive[] PROGMEM = "overdrive";
static const prog_char str_res__fm[] PROGMEM = "fm";
static const prog_char str_res_flavour[] PROGMEM = "flavour";
static const prog_char str_res_time[] PROGMEM = "time";
static const prog_char str_res_level[] PROGMEM = "level";
static const prog_char str_res_fdb[] PROGMEM = "fdb";
static const prog_char str_res_feedback[] PROGMEM = "feedback";
static const prog_char str_res_eq_[] PROGMEM = "eq.";
static const prog_char str_res_fdbck_eq_[] PROGMEM = "fdbck eq.";
static const prog_char str_res_tempo[] PROGMEM = "tempo";
static const prog_char str_res_bpm[] PROGMEM = "bpm";
static const prog_char str_res_groove[] PROGMEM = "groove";
static const prog_char str_res_direction[] PROGMEM = "direction";
static const prog_char str_res_pattern[] PROGMEM = "pattern";
static const prog_char str_res_division[] PROGMEM = "division";
static const prog_char str_res_start[] PROGMEM = "start";
static const prog_char str_res_length[] PROGMEM = "length";
static const prog_char str_res_octave[] PROGMEM = "octave";
static const prog_char str_res_raga[] PROGMEM = "raga";
static const prog_char str_res_porta[] PROGMEM = "porta";
static const prog_char str_res_prt[] PROGMEM = "prt";
static const prog_char str_res_legato[] PROGMEM = "legato";
static const prog_char str_res_tuning[] PROGMEM = "tuning";
static const prog_char str_res_midi_chan[] PROGMEM = "midi chan";
static const prog_char str_res_chn[] PROGMEM = "chn";
static const prog_char str_res_midi_out[] PROGMEM = "midi out";
static const prog_char str_res_pause[] PROGMEM = "pause";
static const prog_char str_res_startpage[] PROGMEM = "startpage";
static const prog_char str_res_snap[] PROGMEM = "snap";
static const prog_char str_res_oscillator_1[] PROGMEM = "oscillator 1";
static const prog_char str_res_oscillator_2[] PROGMEM = "oscillator 2";
static const prog_char str_res_mixer[] PROGMEM = "mixer";
static const prog_char str_res_filter[] PROGMEM = "filter";
static const prog_char str_res_filterS[] PROGMEM = "filter+";
static const prog_char str_res_mode_1[] PROGMEM = "mode 1";
static const prog_char str_res_mode_2[] PROGMEM = "mode 2";
static const prog_char str_res_md1[] PROGMEM = "md1";
static const prog_char str_res_md2[] PROGMEM = "md2";
static const prog_char str_res_envelope_1[] PROGMEM = "envelope 1";
static const prog_char str_res_envelope_2[] PROGMEM = "envelope 2";
static const prog_char str_res_sequencer[] PROGMEM = "sequencer";
static const prog_char str_res_arpeggio[] PROGMEM = "arpeggio";
static const prog_char str_res_ch1[] PROGMEM = "ch1";
static const prog_char str_res_ch2[] PROGMEM = "ch2";
static const prog_char str_res_11[] PROGMEM = "1";
static const prog_char str_res_12[] PROGMEM = "2";
static const prog_char str_res_step_sequencer[] PROGMEM = "step sequencer";
static const prog_char str_res_keyboard[] PROGMEM = "keyboard";
static const prog_char str_res_midi[] PROGMEM = "midi";
static const prog_char str_res_system[] PROGMEM = "system";
static const prog_char str_res_performance[] PROGMEM = "performance";
static const prog_char str_res_param__1[] PROGMEM = "param. 1";
static const prog_char str_res_param__2[] PROGMEM = "param. 2";
static const prog_char str_res_pr1[] PROGMEM = "pr1";
static const prog_char str_res_pr2[] PROGMEM = "pr2";
static const prog_char str_res_fx_[] PROGMEM = "fx.";
static const prog_char str_res_fx_prog_[] PROGMEM = "fx prog.";
static const prog_char str_res_lpf[] PROGMEM = "lpf";
static const prog_char str_res_bpf[] PROGMEM = "bpf";
static const prog_char str_res_hpf[] PROGMEM = "hpf";
static const prog_char str_res_lpl[] PROGMEM = "lp<";
static const prog_char str_res_bpl[] PROGMEM = "bp<";
static const prog_char str_res_hpl[] PROGMEM = "hp<";
static const prog_char str_res_Slp[] PROGMEM = "+lp";
static const prog_char str_res_Sbp[] PROGMEM = "+bp";
static const prog_char str_res_Shp[] PROGMEM = "+hp";
static const prog_char str_res_glp[] PROGMEM = ">lp";
static const prog_char str_res_gbp[] PROGMEM = ">bp";
static const prog_char str_res_ghp[] PROGMEM = ">hp";
static const prog_char str_res_lp4[] PROGMEM = "lp4";
static const prog_char str_res_lp3[] PROGMEM = "lp3";
static const prog_char str_res_lp2[] PROGMEM = "lp2";
static const prog_char str_res_lp1[] PROGMEM = "lp1";
static const prog_char str_res_hp1[] PROGMEM = "hp1";
static const prog_char str_res_hp2[] PROGMEM = "hp2";
static const prog_char str_res_hp3[] PROGMEM = "hp3";
static const prog_char str_res_bp2[] PROGMEM = "bp2";
static const prog_char str_res_bp4[] PROGMEM = "bp4";
static const prog_char str_res_notch[] PROGMEM = "notch";
static const prog_char str_res_phaser[] PROGMEM = "phaser";
static const prog_char str_res_h2lp[] PROGMEM = "h2lp";
static const prog_char str_res_h3lp[] PROGMEM = "h3lp";
static const prog_char str_res_nSlp[] PROGMEM = "n+lp";
static const prog_char str_res_pSlp[] PROGMEM = "p+lp";
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

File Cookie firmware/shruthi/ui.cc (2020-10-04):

// Copyright 2013 Olivier Gillet.
//
// Author: Olivier Gillet (ol.gillet@gmail.com)
//
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
// -----------------------------------------------------------------------------
//
// User interface handler.

#include "shruthi/ui.h"

#include "shruthi/editor.h"
#include "shruthi/part.h"

namespace shruthi {

using namespace avrlib;

/* static */
bool Ui::inhibit_shift_release_;
bool Ui::inhibit_encoder_release_;
uint8_t Ui::switch_state_[SWITCH_LAST];
uint32_t Ui::switch_delay_[SWITCH_LAST];
uint8_t Ui::sub_clock_;
uint8_t Ui::sub_clock_2_;
uint8_t Ui::progress_bar_;
uint8_t Ui::led_pattern_;
uint8_t Ui::led_pwm_counter_;
uint8_t Ui::pots_multiplexer_address_;
int16_t Ui::adc_values_[36];
int8_t Ui::adc_thresholds_[36];
uint8_t Ui::adc_warm_up_cycles_;
uint8_t Ui::adc_hot_address_;
uint8_t Ui::adc_resume_scan_to_;
uint32_t Ui::idle_time_;
bool Ui::freeze_display_;
Adc Ui::adc_;
EventQueue<> Ui::queue_;
SpiMaster<IOEnableLine, MSB_FIRST, 4> Ui::io_;
SpiMaster<IOEnableLineAux, MSB_FIRST, 4> Ui::aux_io_;
RotaryEncoder<EncoderALine, EncoderBLine, EncoderClickLine> Ui::encoder_;

static const int16_t kAdcThresholdLocked = 32;
static const int16_t kAdcThresholdUnlocked = 8;

/* static */
void Ui::Init() {
  io_.Init();
  aux_io_.Init();
  encoder_.Init();

  lcd.Init();
  display.Init();
  lcd.SetCustomCharMapRes(character_table[0], (CHR_RES_SPECIAL_CHARACTERS_SIZE / 8), 1);

  editor.Init();
  queue_.Flush();

  progress_bar_ = 0;
  pots_multiplexer_address_ = 0;

  inhibit_shift_release_ = false;
  memset(switch_state_, 0xff, sizeof(switch_state_));
  
  adc_.Init();
  adc_.set_reference(ADC_DEFAULT);
  adc_.set_alignment(ADC_RIGHT_ALIGNED);
  adc_.StartConversion(0);
  pots_multiplexer_address_ = 0;
    
  for (uint8_t i = 0; i < 36; ++i) {
    adc_values_[i] = -1;
    adc_thresholds_[i] = kAdcThresholdUnlocked;
  }
  adc_warm_up_cycles_ = 8;
  adc_hot_address_ = 0;
  adc_resume_scan_to_ = 0;
}

/* static */
void Ui::ShowSplash() {
  if (!encoder_.immediate_value()) {
    SystemSettings* settings = part.mutable_system_settings();
    settings->programmer = settings->programmer + 1;
    if (settings->programmer > PROGRAMMER_XT) {
      settings->programmer = 0;
    }
    settings->EepromSave();
    editor.DisplaySplashScreen(
        STR_RES_SHRUTHI_CLASSIC + (settings->programmer << 1));
    freeze_display_ = true;
  } else if (part.system_settings().start_page == START_PAGE_SPLASH) {
    editor.DisplaySplashScreen(STR_RES_V + 1);
  } else if (part.system_settings().start_page == START_PAGE_LAST_PATCH) {
    editor.BootOnPatchBrowsePage(part.system_settings().last_patch);
  } else {
    editor.Refresh();
  }
}

/* static */
void Ui::LockPotentiometers() {
  uint8_t programmer = part.system_settings().programmer;
  adc_thresholds_[0] = kAdcThresholdLocked;
  adc_thresholds_[1] = kAdcThresholdLocked;
  adc_thresholds_[2] = kAdcThresholdLocked;
  adc_thresholds_[3] = kAdcThresholdLocked;
}

const prog_uint8_t xt_parameter_mapping[] PROGMEM = {
  4 + 29,  // PRM_LFO_ATTACK_2
  4 + 30,  // PRM_LFO_RATE_2
  4 + 26,  // PRM_LFO_RATE_1
  4 + 25,  // PRM_LFO_ATTACK_1
  4 + 20,  // PRM_ENV_ATTACK_2
  4 + 23,  // PRM_ENV_RELEASE_2
  4 + 21,  // PRM_ENV_DECAY_2
  4 + 22,  // PRM_ENV_SUSTAIN_2
  
  4 + 18,  // PRM_ENV_SUSTAIN_1
  4 + 17,  // PRM_ENV_DECAY_1
  4 + 31,  // SOFTWARE VOLUME
  4 + 19,  // PRM_ENV_RELEASE_1
  4 + 16,  // PRM_ENV_ATTACK_1
  0xff,  // Unassigned
  0xff,  // Unassigned
  0xff,  // Unassigned
  
  4 + 6,  // PRM_OSC_RANGE_2
  4 + 1,  // PRM_OSC_PARAMETER_1
  4 + 5,  // PRM_OSC_PARAMETER_2
  4 + 2,  // PRM_OSC_RANGE_1
  4 + 7,  // PRM_OSC_OPTION_2
  4 + 10, // PRM_MIX_SUB_OSC
  4 + 9,  // PRM_MIX_BALANCE
  4 + 11, // PRM_MIX_NOISE
  
  0,
  1,
  2,
  3,
  4 + 12,  // PRM_FILTER_CUTOFF
  4 + 13,  // PRM_FILTER_RESONANCE
  4 + 14,  // PRM_FILTER_ENV
  4 + 15,  // PRM_FILTER_LFO
};

/* static */
void Ui::ScanPotentiometers() {
  adc_.Wait();
  uint8_t address = pots_multiplexer_address_;
  uint8_t physical_address = address;
  int16_t value = adc_.ReadOut();
  
  if (part.system_settings().programmer == PROGRAMMER_NONE) {
    *PortA::Mode::ptr() = 0x00;
    pots_multiplexer_address_ = (pots_multiplexer_address_ + 1) & 7;
    if (adc_resume_scan_to_ == 0) {
      adc_resume_scan_to_ = pots_multiplexer_address_ + 1;
      pots_multiplexer_address_ = adc_hot_address_;
    } else {
      pots_multiplexer_address_ = adc_resume_scan_to_ - 1;
      adc_resume_scan_to_ = 0;
    }    
    adc_.StartConversion(pots_multiplexer_address_);
    if (address >= 4) {
      value = 1023 - value;   // Cookie: invert external CV inputs CV1..4
      part.mutable_voice()->set_modulation_source(
          MOD_SRC_CV_1 + address - 4, value >> 2);
      address = 0xff;
    }
  } else if (part.system_settings().programmer == PROGRAMMER_FCD) {
    *PortA::Mode::ptr() = 0x00;
    pots_multiplexer_address_++;
    if (pots_multiplexer_address_ >= 36) {
      pots_multiplexer_address_ = 0;
    }
    if (pots_multiplexer_address_ < 4) {
      adc_.StartConversion(pots_multiplexer_address_);
    } else {
      WriteShiftRegister();
      adc_.StartConversion(4);
    }
  } else if (part.system_settings().programmer == PROGRAMMER_XT) {
    *PortA::Mode::ptr() = 0xfe;
    pots_multiplexer_address_ = (pots_multiplexer_address_ + 1) & 31;
    if (adc_resume_scan_to_ == 0) {
      adc_resume_scan_to_ = pots_multiplexer_address_ + 1;
      pots_multiplexer_address_ = adc_hot_address_;
    } else {
      pots_multiplexer_address_ = adc_resume_scan_to_ - 1;
      adc_resume_scan_to_ = 0;
    }    
    uint8_t byte = (pots_multiplexer_address_ << 1) & 0x0f;
    uint8_t range = pots_multiplexer_address_ >> 3;
    byte |= (~(0x10 << range)) & 0xf0;
    *PortA::Output::ptr() = byte;
    adc_.StartConversion(0);
    address = pgm_read_byte(xt_parameter_mapping + address);
  }
  
  if (address != 0xff) {
    if (adc_warm_up_cycles_) {
      // Register the value and move on.
      adc_values_[address] = value;
      if (address == 0) {
        --adc_warm_up_cycles_;
        if (adc_warm_up_cycles_ == 0) {
          // Send a message for the volume knob
          if (part.system_settings().programmer == PROGRAMMER_XT) {
            queue_.AddEvent(CONTROL_POT, 35, adc_values_[35]);
          }
        }
      }
    } else {
      int16_t previous_value = adc_values_[address];
      int16_t delta = value - previous_value;
      int16_t threshold = adc_thresholds_[address];
      if (delta > threshold || delta < -threshold) {
        adc_hot_address_ = physical_address;
        adc_thresholds_[address] = kAdcThresholdUnlocked;
        queue_.AddEvent(CONTROL_POT, address, value >> 3);
        adc_values_[address] = value;
      }
    }
  }
}
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

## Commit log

2020-09-09 name of filter board corrected
2020-10-04 Update Cookie Synth assembly instructions.pdf

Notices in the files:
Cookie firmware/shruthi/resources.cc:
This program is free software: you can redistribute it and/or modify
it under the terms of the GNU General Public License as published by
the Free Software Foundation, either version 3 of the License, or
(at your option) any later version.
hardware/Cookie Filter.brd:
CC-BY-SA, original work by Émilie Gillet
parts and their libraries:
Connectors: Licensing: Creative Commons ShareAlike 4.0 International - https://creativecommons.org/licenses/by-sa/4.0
